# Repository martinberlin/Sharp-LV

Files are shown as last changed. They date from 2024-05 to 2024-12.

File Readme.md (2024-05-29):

### Sharp Low Consumption Versatile PCB

This will host the PCB KiCad files for a  board that aims to be a low consumption driver for SHARP 2.7" MIP LCDs with optional touch.
This is a current work in project and by any means ready to send anywhere to production. The factory we use to produce our prototypes and final PCBs is [JLCPCB.com](https://jlcpcb.com)

### How with touch ?

The person that sold this in eBay had a BTC wallet project that didn't see the light as a product, and combined a Microchip Atmel capacitive touch with a Sharp 400x240 memory LCD:

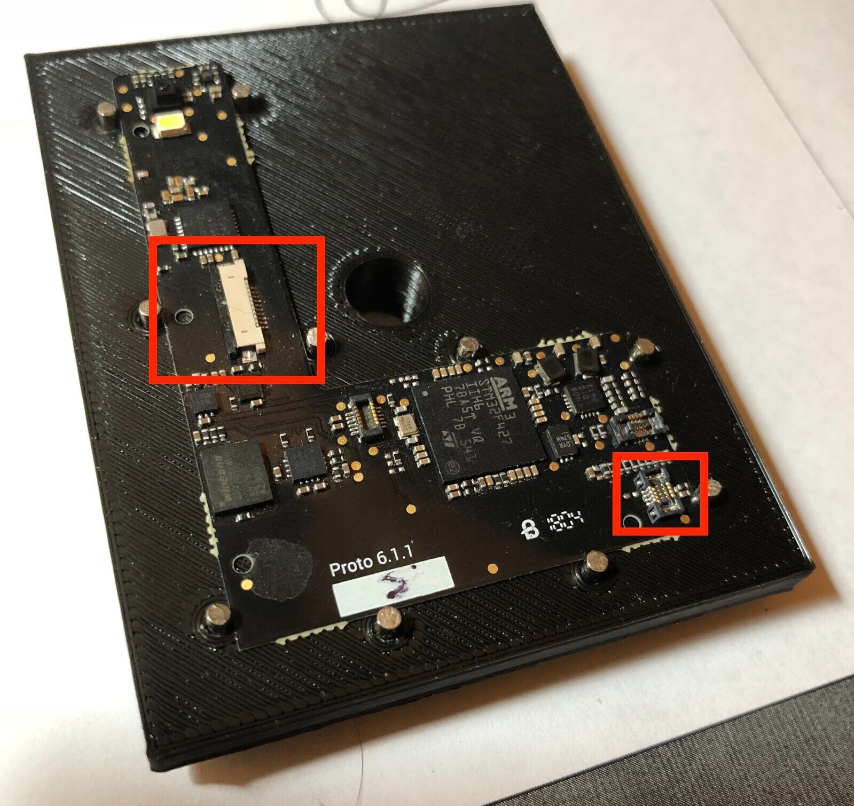
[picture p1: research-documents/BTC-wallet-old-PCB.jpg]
BTC Wallet


Resulting in that he has a nice amount of this combination to sell in eBay.

**TOUCH PINOUT**

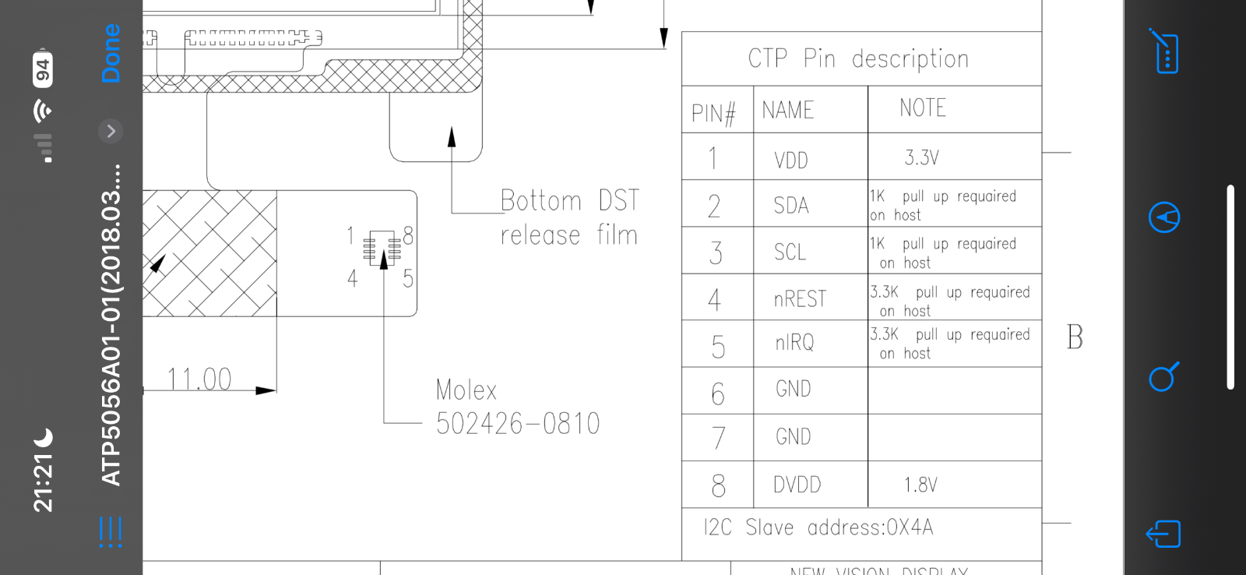
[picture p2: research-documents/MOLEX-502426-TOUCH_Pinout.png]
Atmel pinout


### Goals to achieve with this board

Just a quick wishlist for this PCB wishes, in version 1.0 just want to get the basics working, no add-ons maybe just a QWIIC connector that is cheap:

1. Display working with external Resonator CrystalFonts RV3032 so the MCU can go to sleep and we can keep the LCD running
2. touch connector with the Molex part  C563931
3. Ready for LVGL
4. BLE working at least for 20 meters receiving and sending data packages

### Reference working designs 

[Altium example for nRF52](https://resources.altium.com/p/getting-started-nrf52-mcu-pcb)

[Mike Rankin Oled PCB](https://github.com/mike-rankin/nRF52832_Oled_Board)

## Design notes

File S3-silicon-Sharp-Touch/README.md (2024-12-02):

# SHARP Light and Versatile controller

The goal of this PCB is to make a small SHARP memory in pixel (MIP) controller
All this might change as the idea develops but initially the plan is the following:

- DS3231 or RV2032 acting as RTC to generate the Squarewave required by this displays
- Optional touch only available in eBay from a seller in the UK (Better use 1.1 version)

3D PCB

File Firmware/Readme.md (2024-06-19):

## MaxTouch MXT144

Thanks to Larry Bank [@bitbank2](https://github.com/bitbank2) to be the firt one making the touch work with his [bb_captouch](https://github.com/bitbank2/bb_captouch/) library.
Just load in Arduino IDE the [MaxTouchSharp](https://github.com/martinberlin/Sharp-LV/tree/main/Firmware/MaxTouchSharp) folder. Select any board and connect I2C plus RST pin to the microcontroller. Does not need in my opinion pullup resistances for a quick test although there will be added in the PCB.

### Additional challenge with this MaxTouch device

We should check the [mXT144U Datasheet](https://www.microchip.com/content/dam/mchp/documents/OTH/ProductDocuments/DataSheets/mXT144U%20Touchscreen%20Controller%20Product%20Datasheet.pdf) and see if there is an "interrupt mode" where IRQ pin stays HIGH and goes low when there are messages pending to be read.

### 2 flavours of PCB being designed

1. **Nordic nRF52840** BLE only/ Low consumption (And low experience from my side) you can preview it in this repository, all files open source and MIT licensed. Reviewed by the super helpful and friendly [Nordic engineers in the devZone](https://devzone.nordicsemi.com/f/nordic-q-a/112090/schematics-sanity-check-for-a-sharp-lcd-controller-using-nrf52840)

2. **ESP32-S3FN8** silicon only board w/ BLE & Wi-Fi, made one before so the experience is a bit higher, this one is not **low consumption**. But at least is 240 Mhz and we could try boosting Sharp with LVGL to the max. possible speed.
[Preview both here](https://github.com/martinberlin/Sharp-LV/wiki/PCBs-being-made)

S3 PCB version

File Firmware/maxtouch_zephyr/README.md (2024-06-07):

## Overview

   - For the moment scans I2C addresses in Zephyr

The I2C pins are defined in /boards/espressif/esp32s2_devkitc-pinctrl.dtsi

 :ref:`i2c0_default`.

For the moment I just edited that file manually since I don't know exactly how to extend it in the overlay:

```
 	i2c0_default: i2c0_default {
		group1 {
			pinmux = <I2C0_SDA_GPIO0>,
				 <I2C0_SCL_GPIO1>;
			bias-pull-up;
			drive-open-drain;
			output-high;
		};
	};
```

The source code shows how to:

1. Instance I2C
2. Scan the addresses from 1 to 127
3. Output the first device found and it's address

Requirements
************

Your board must:

* Have I2C enabled, connected to the device, and it must be powered
* Maybe will need pullups in the SDA, SCL lines depending on the device you use

Adding board support
********************

The idea is to port this to a nRF52 but I'm still a newbie on Zephyr!
There is a lot to learn still.

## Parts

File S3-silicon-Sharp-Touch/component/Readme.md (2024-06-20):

### PCB Components

This folder has Symbols, Footprints and 3D Models that are only for this project.

PCB footprint antenna belongs to https://github.com/prasad-dot-ws
and I'm unsure to use it in this design because it does not show the compensated circuit.
This RF tunning needs to be made per board. Is not something you can just copy and paste around.

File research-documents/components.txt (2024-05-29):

COMPONENTS Research & Reference notes

MOLEX female connector
0.4mm 2 Brick nogging Female SMD,P=0.4mm Board-to-Board and Backplane Connector ROHS
https://jlcpcb.com/partdetail/Molex-5024260810/C563931

MCU
https://jlcpcb.com/partdetail/NordicSemicon-NRF52840_QIAAR/C190794 costs 3.05 USD buying 10.

Pin-out:
1..8  1 VDD 3.3V         5   nIRQ (INT) 3.3K pullup
 ||   2 SDA              6&7 GND
4..5  3 SCL
      4 nRST 3.3K pullup

External RTC to make a 50/50 Squarewave for the LCD

https://jlcpcb.com/partdetail/C5127802 
    I2C SON-8(1.5x3.2) Real-Time Clocks(RTC) ROHS

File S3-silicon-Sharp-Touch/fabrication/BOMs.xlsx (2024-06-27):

Designator | Footprint | Comment | JLCPCB Part #
J1 | USB_C_Receptacle_HRO_TYPE-C-31-M-12 | USB_C_Receptacle_USB2.0 | C165948
R3,R5,R6 | R_0603_1608Metric | 10k | C25804
X1 | Crystal_ECS-40Mhz_ECS | Crystal 40 Mhz 10ppm | C555614
C4,C1,C2 | C_0805_2012Metric | 10uF | C15850
RN1 | R_Array_Concave_4x0402 | R_Pack04 | C728735
C7,C6,C5,C8 | C_0603_1608Metric | 0.1uF | C3846795
L1,L2 | L_0603_1608Metric | L | C1027
R1,R11,R14,R15 | R_0603_1608Metric | 5.1k | C23186
D6 | LED_0805_2012Metric | GRE | C2297
R7,R8,R9,R10 | R_0402_1005Metric | 3.3k | C5224103
Q2,Q1 | SOT-23 | MMBT3904 | C20526
D2,D1,D4,D3 | LED_0805_2012Metric | LED | C2297
BT1 | CoinBattery_MS621FE | Battery_Cell | C80909
J6 | CON_Molex_5024260812 | 5024260810 | C563931
C3,C9 | C_0603_1608Metric | 1uF | C525331
Q3 | SOT-23 | Si2301CDS | C10487
C15,C14 | C_0805_2012Metric | 12pF | C1792
C10,C11 | C_0603_1608Metric | 22pF | C561172
R4 | R_0603_1608Metric | 0Ω | C21189
C12 | C_0603_1608Metric | 2pF | C162216
R13 | R_0805_2012Metric | 2K2 | C17520
J7 | S2BPHSM4TBLFSN | S2B-PH-SM4-TB_LF__SN_ | C295747
Y1 | Crystal_SMD_3215-2Pin_3.2x1.5mm | 32.768K | C32346
U4 | SOIC-8_3.9x4.9mm_P1.27mm | DS3231MZ | C107410
IC1 | ESP32-S3FN8-QFN40P700X700X90-57N-D | ESP32-S3FN8 | C2913196
D5 | D_SOD-123 | 1N5817 | C8598
U1 | TSOT-23-5 | RT9080-33GJ5 | C841192
R16 | R_0603_1608Metric | 10 K | C25804
C13 | C_0603_1608Metric | 2.4pF | C5448887
D7 | LED_0805_2012Metric | RED | C84256
U3 | TP4057-42-SOT26-R | TP4057-42-SOT26-R | C12044
ANT1 | 2450AT42E0100E-ANT | 2450AT42E0100E | C3285081
R12 | R_0603_1608Metric | 10K | C25804
J5 | FH5210S05SH99_LCD | FH52-10S-0.5SH_99 | C598038
U2 | SOT-666 | USBLC6-2P6 | C2827693

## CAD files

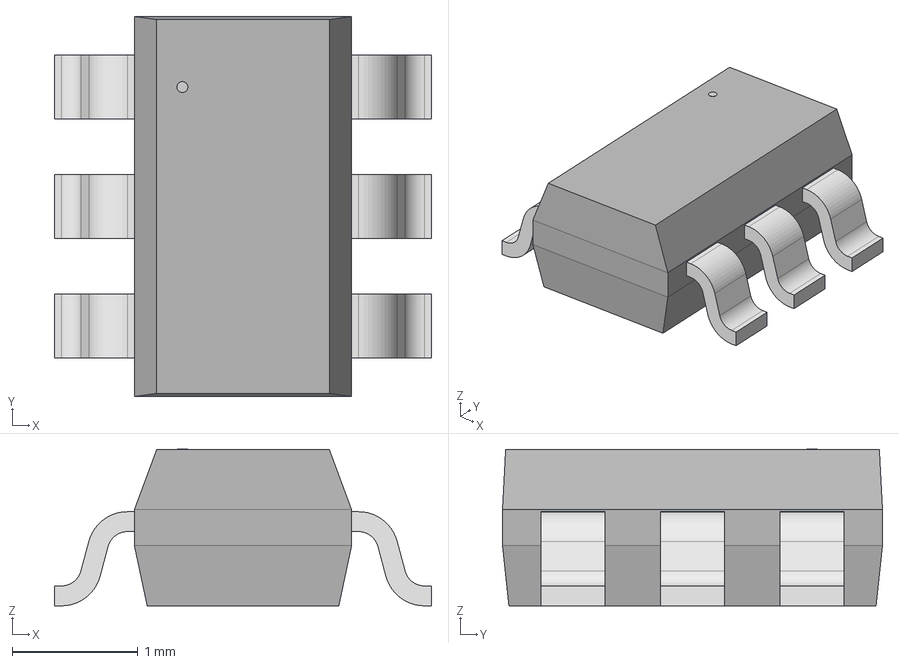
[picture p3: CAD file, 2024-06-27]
components/3D/TP4057-SOT-23.step
3.00 x 3.02 x 1.25 mm

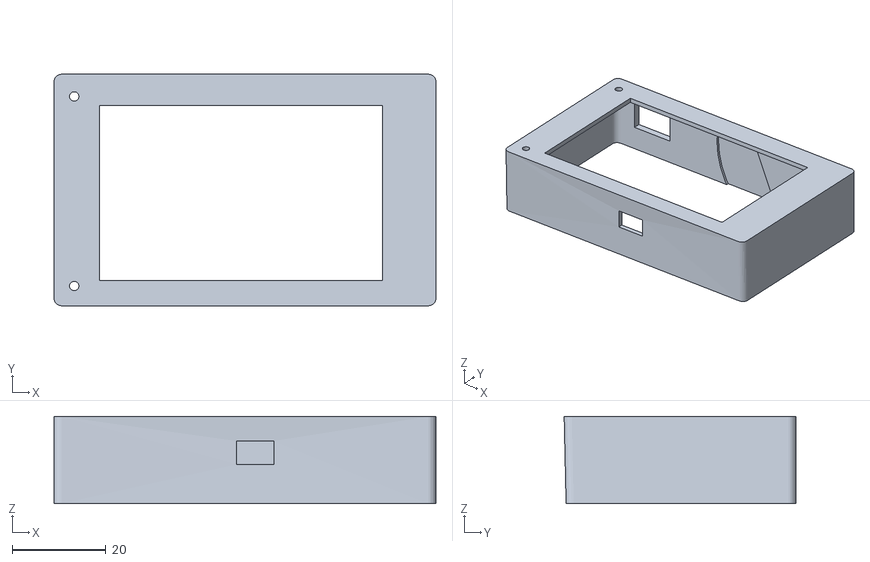
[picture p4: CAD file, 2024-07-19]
enclosure/SHARP-S3-battery-TOP.stl
81.4 x 49.4 x 18.6

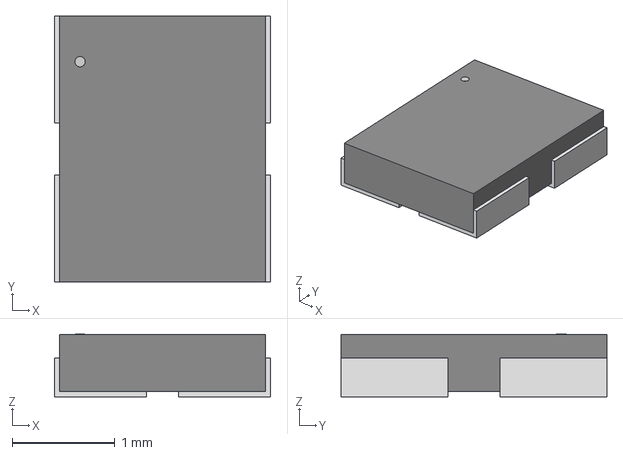
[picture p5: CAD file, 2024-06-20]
S3-silicon-Sharp-Touch/component/3d/Crytal_ECS-40Mhz_ECS.step
2.11 x 2.59 x 0.612 mm

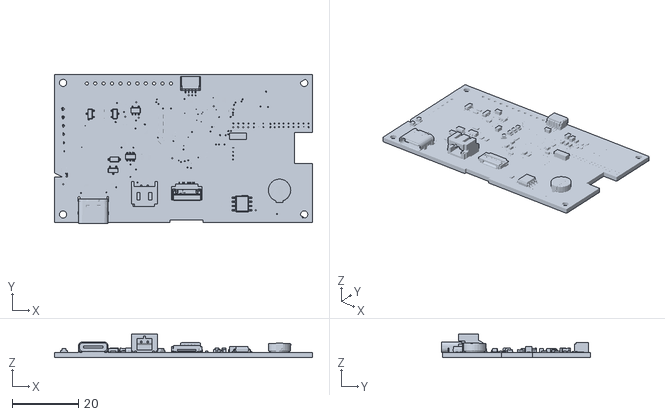
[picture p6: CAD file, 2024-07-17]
S3-silicon-Sharp-Touch/fabrication/3D/S3-silicon-Sharp-Touch-3D.stl
77.9 x 44.8 x 7.17

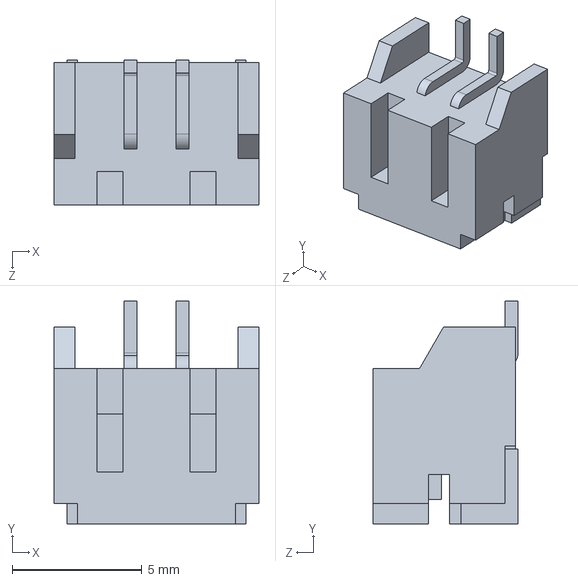
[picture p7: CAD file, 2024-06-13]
components/3D/S2B-PH-SM4-TB_LF__SN_.stp
7.90 x 8.60 x 5.60 mm

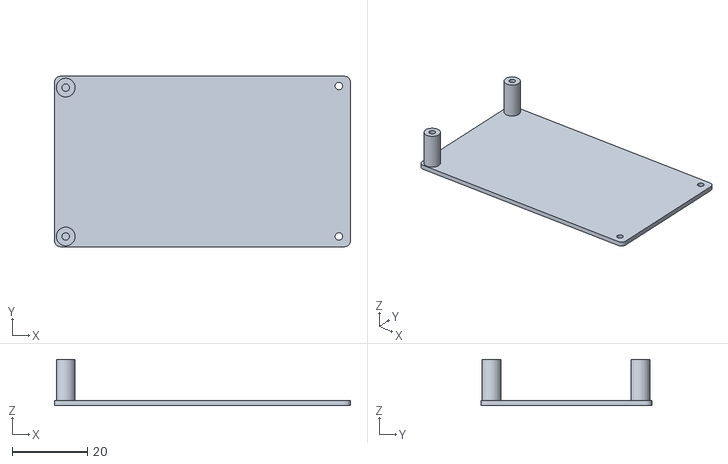
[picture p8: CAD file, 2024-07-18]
enclosure/SHARP-S3-battery-BOTTOM.stl
78.8 x 45.4 x 12.3

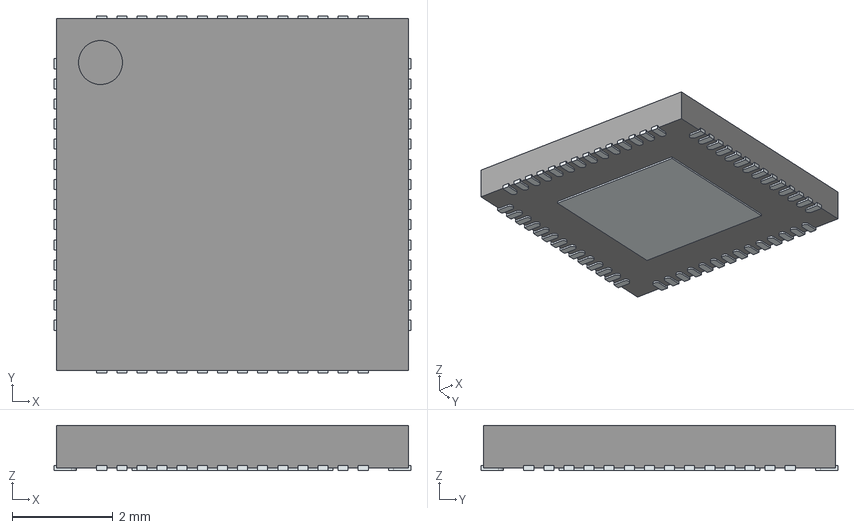
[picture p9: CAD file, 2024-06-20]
S3-silicon-Sharp-Touch/component/3d/ESP32-S3FN8.stp
7.10 x 7.10 x 0.9 mm
ThermalPin
PinsArrayLR
PinsArrayTB

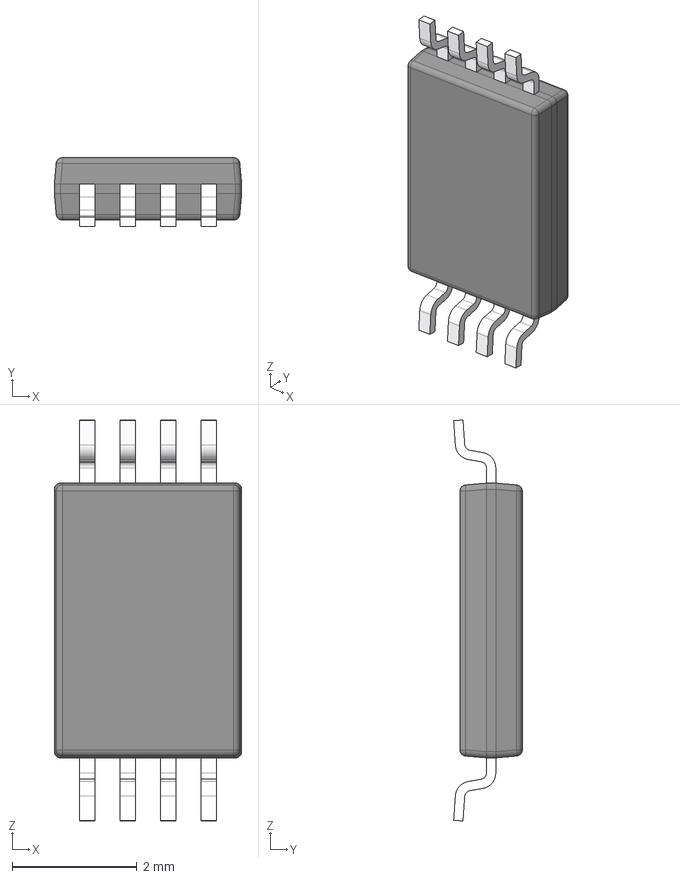
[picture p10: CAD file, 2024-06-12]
components/3D/TPS2113APWR.stp
3.00 x 1.10 x 6.42 mm
BODY-SO
LEAD-SO x 8
PIN1-ID

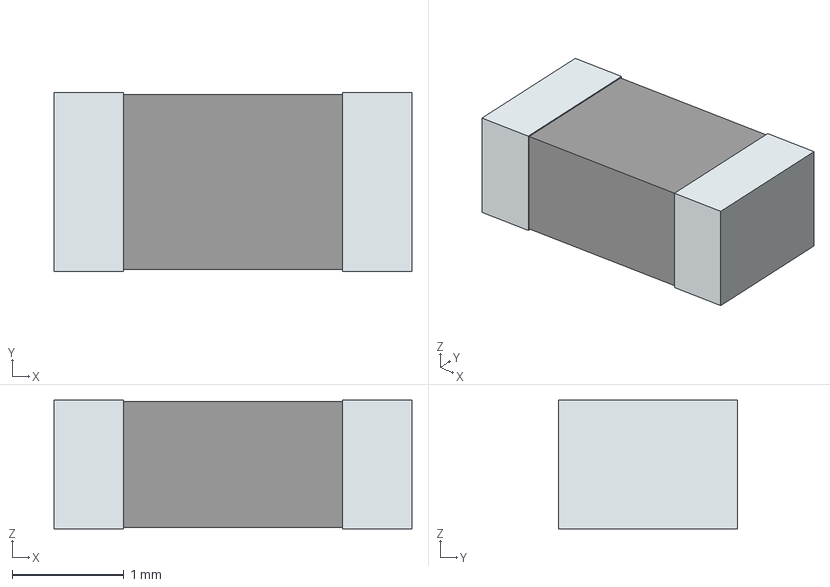
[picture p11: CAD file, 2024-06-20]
S3-silicon-Sharp-Touch/component/3d/W3008-Antenna.step
3.20 x 1.60 x 1.15 mm
term1
term2

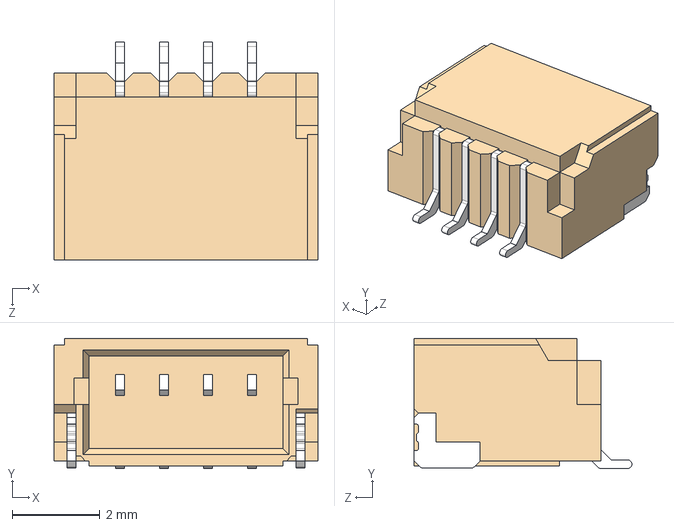
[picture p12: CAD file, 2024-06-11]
components/3D/QWIIC_SM04B-SRSS-TB_LF__SN_.stp
6.00 x 2.96 x 4.95 mm

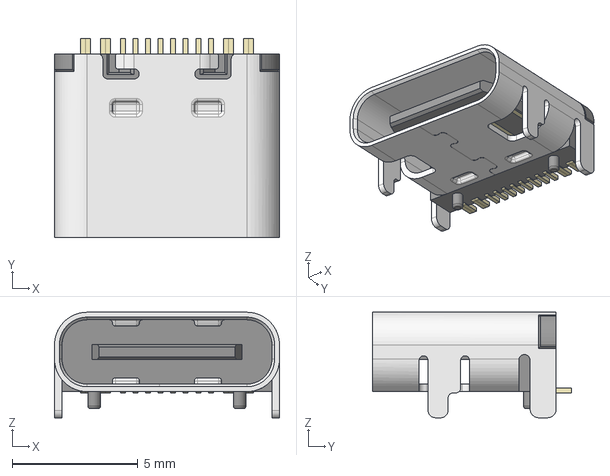
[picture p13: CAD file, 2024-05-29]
S3-silicon-Sharp-Touch/component/3d/USB_TYPE-C-31-M-12.step
8.95 x 7.90 x 4.20 mm

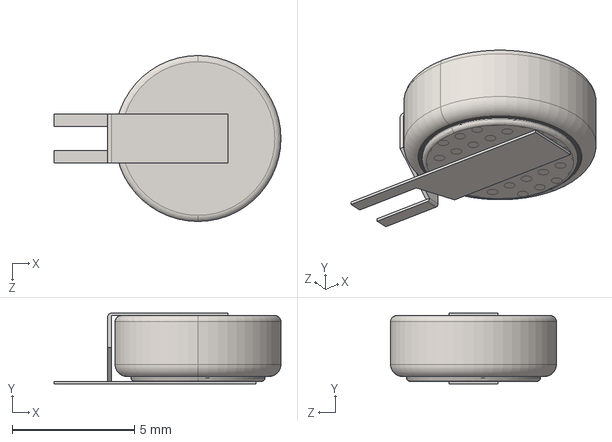
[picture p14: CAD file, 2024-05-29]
components/3D/CoinBattery_MS621FE-FL11E.stp
9.30 x 2.90 x 6.80 mm

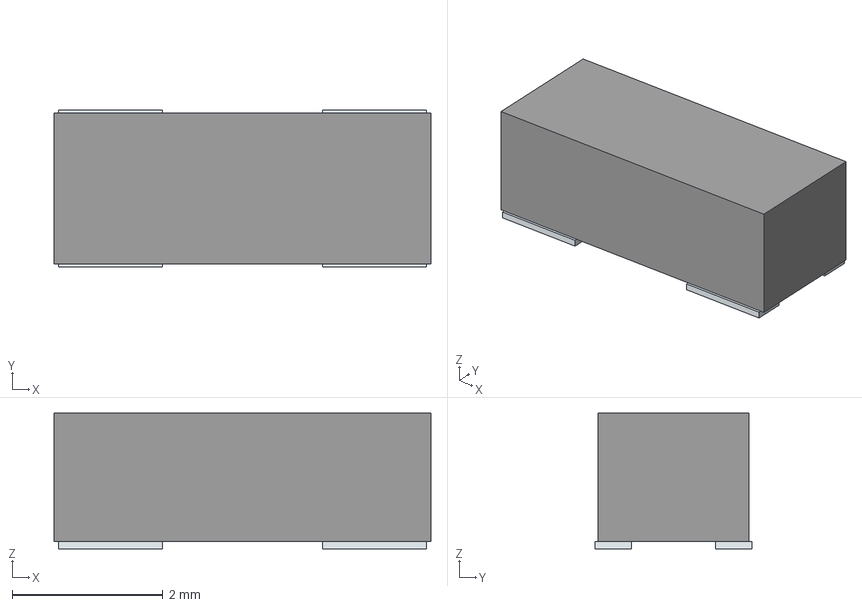
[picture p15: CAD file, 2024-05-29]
S3-silicon-Sharp-Touch/component/3d/2450AT42E0100E-ANT.stp
5.00 x 2.08 x 1.80 mm
Pins

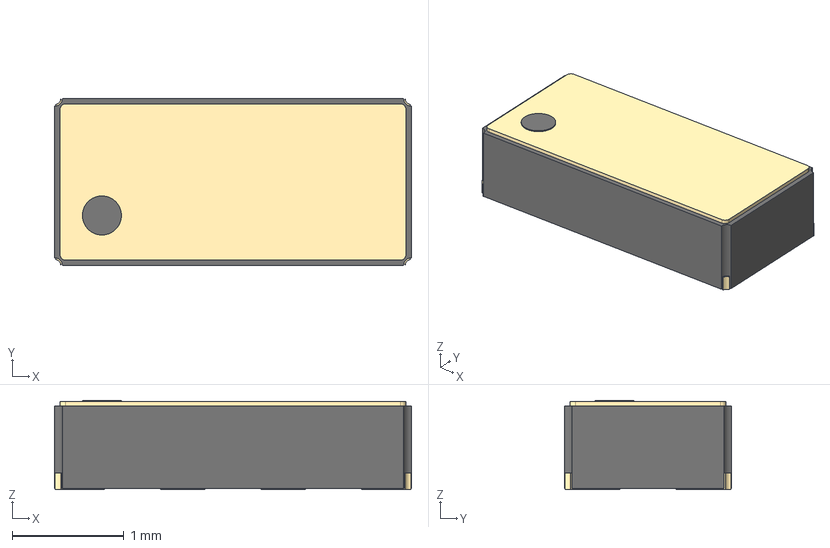
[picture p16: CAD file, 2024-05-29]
components/3D/RV-3032-C7.stp
3.20 x 1.50 x 0.8 mm
Rect2
Rect3
Rect4
Rect5
Terminal

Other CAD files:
components/3D/LCD-10S-0.5SH.step
components/3D/MOLEX_502426-0810.stp
components/3D/NRF52840-QIAA-R.stp
enclosure/SHARP-S3-battery.blend

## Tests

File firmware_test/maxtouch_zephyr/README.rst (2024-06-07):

.. zephyr:code-sample:: maxtouch
   :name: Maxtouch
   :relevant-api: gpio_interface i2c

   For the moment scans I2C addresses in Zephyr

Overview
********

The I2C pins are defined in /boards/espressif/esp32s2_devkitc-pinctrl.dtsi

 :ref:`i2c0_default`.

 For the moment I just edited that file manually since I don't know exactly how to extend it in the overlay:

```
 	i2c0_default: i2c0_default {
		group1 {
			pinmux = <I2C0_SDA_GPIO0>,
				 <I2C0_SCL_GPIO1>;
			bias-pull-up;
			drive-open-drain;
			output-high;
		};
	};
```

The source code shows how to:

#. Instance I2C
#. Scan the addresses from 1 to 127
#. Output the first device found and it's address

Requirements
************

Your board must:

#. Have I2C enabled
#. Maybe will need pullups in the SDA, SCL lines depending on the device you use

Adding board support
********************

The idea is to port this to a nRF52 but I'm still a newbie on Zephyr!
There is a lot to learn still.

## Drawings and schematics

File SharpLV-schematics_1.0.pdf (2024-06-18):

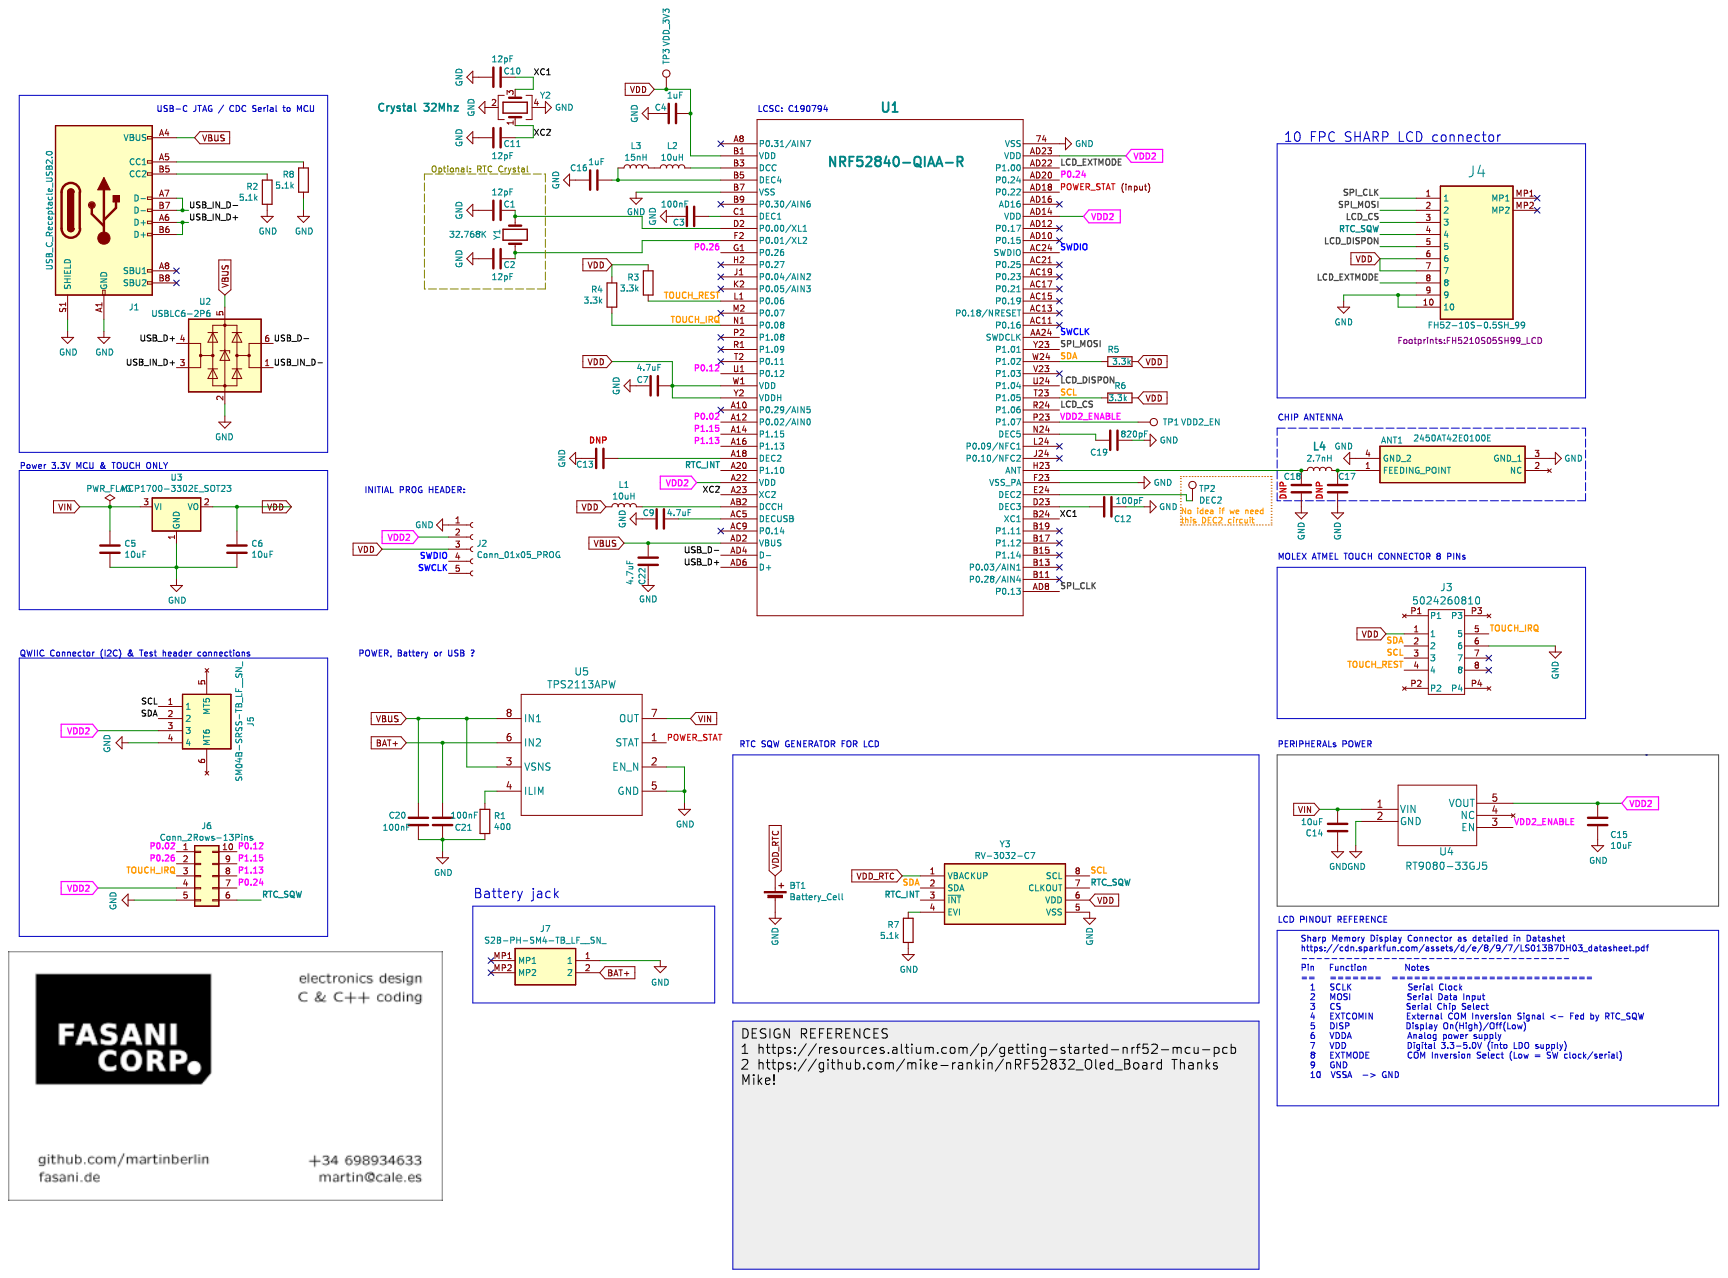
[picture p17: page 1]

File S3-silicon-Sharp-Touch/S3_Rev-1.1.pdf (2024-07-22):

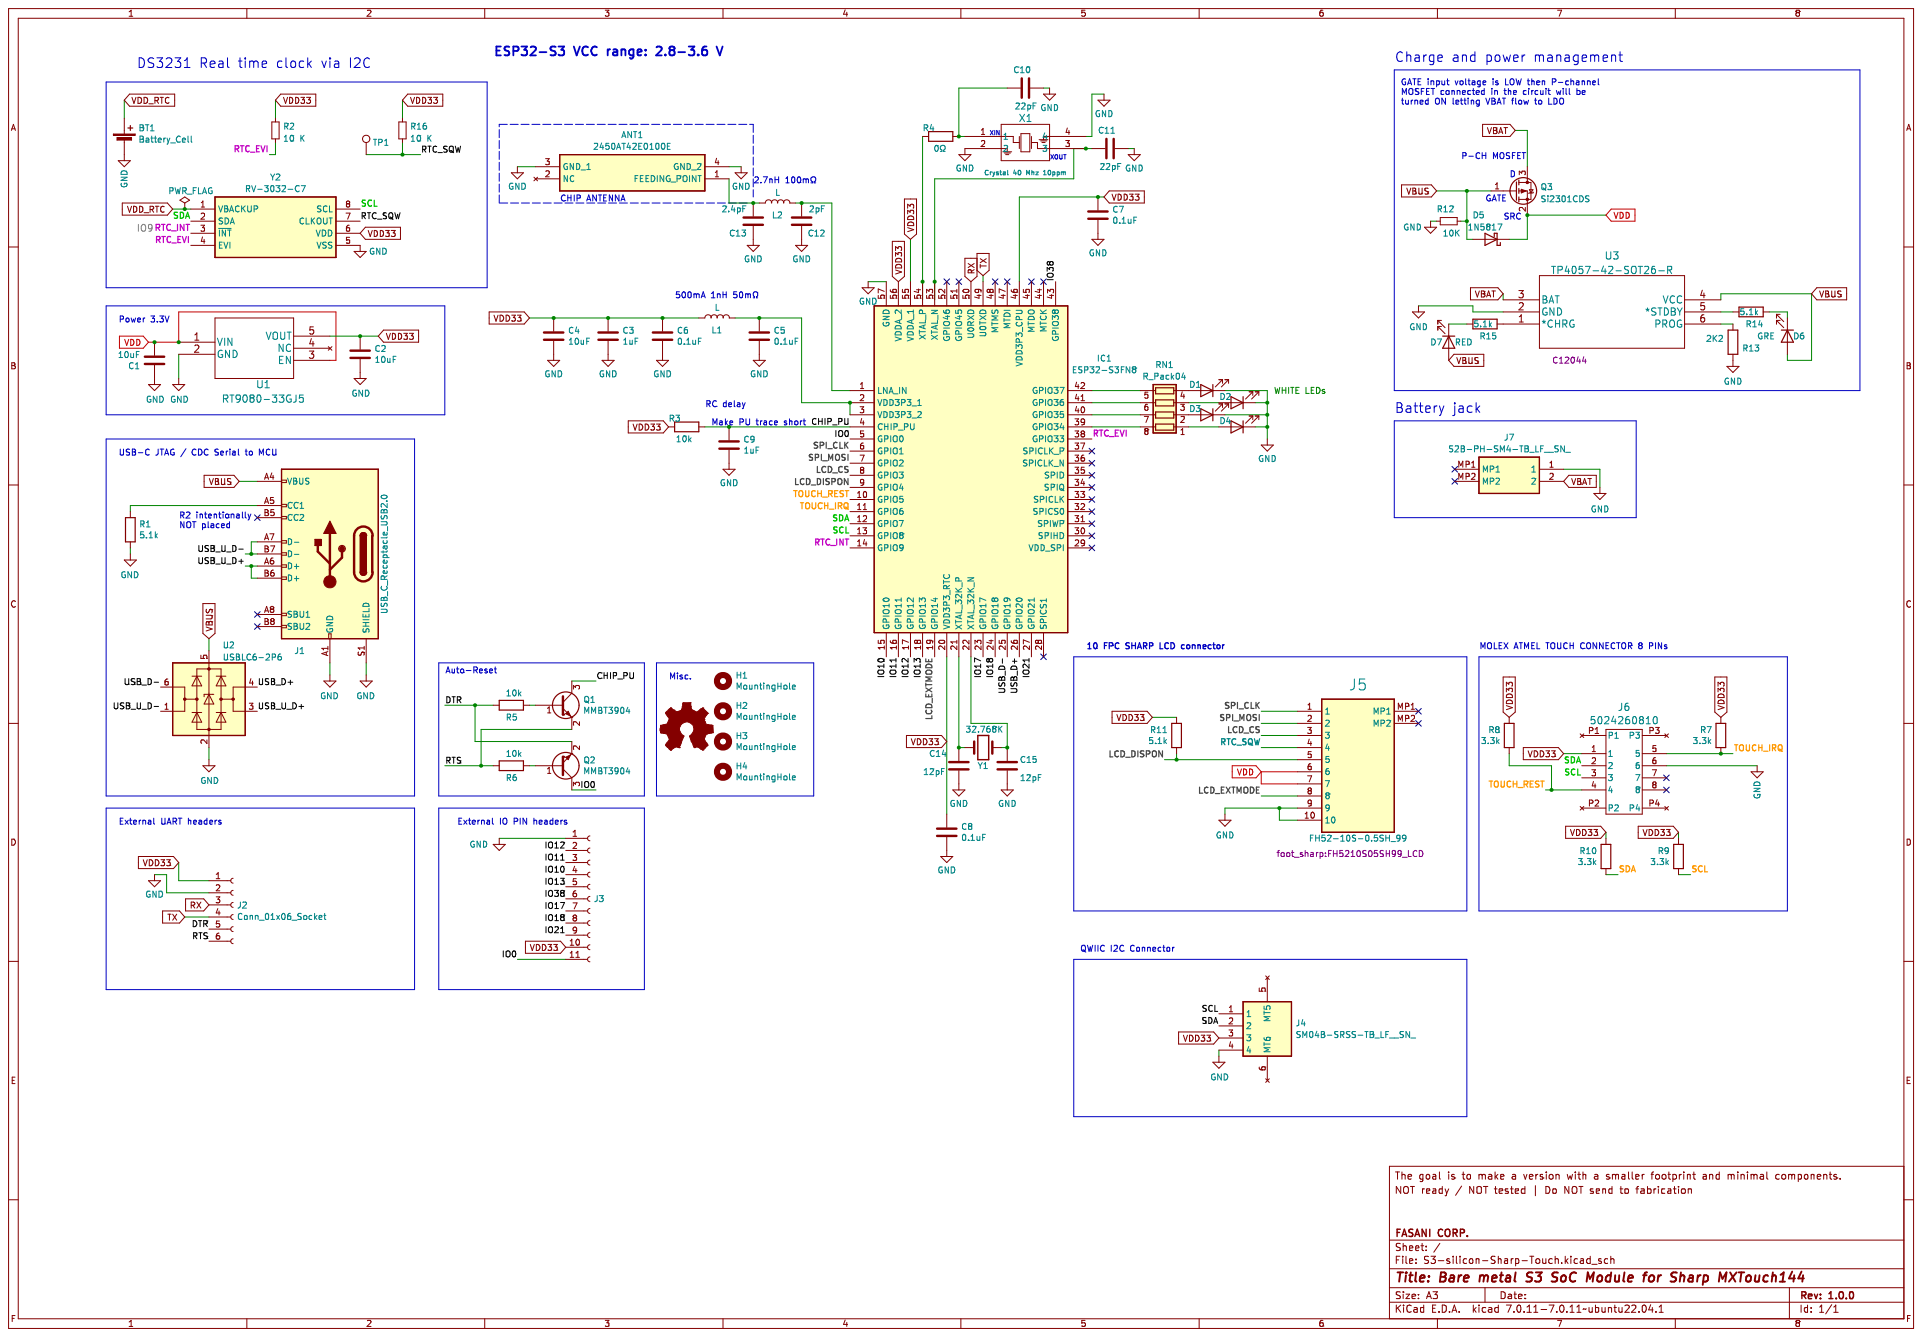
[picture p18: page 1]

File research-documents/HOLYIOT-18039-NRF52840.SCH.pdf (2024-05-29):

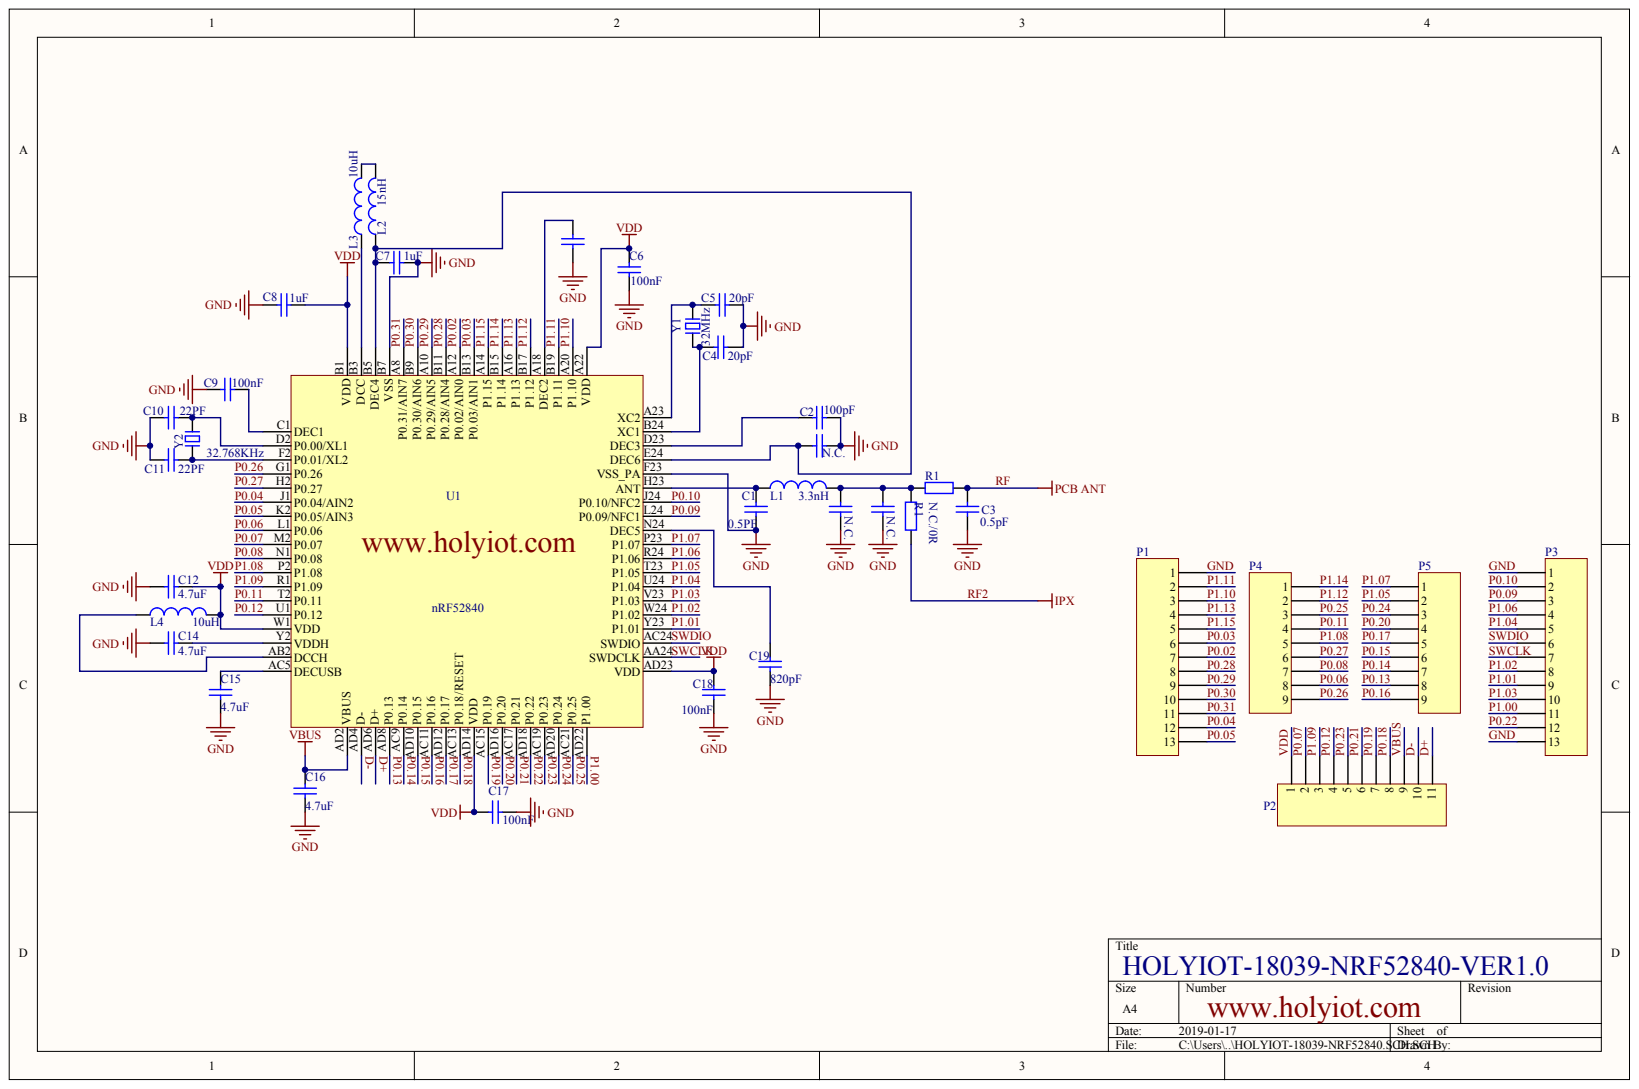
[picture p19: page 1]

VDD AD23 SWDCLK AA24 SWDIO AC24 P1.01 Y23 P1.02 W24 P1.03 V23 P1.04 U24 P1.05 T23 P1.06 R24 P1.07 P23 DEC5 N24 P0.09/NFC1 L24 P0.10/NFC2 J24 ANT H23 VSS_PA F23 DEC6 E24 DEC3 D23 XC1 B24 XC2 A23

VDD A22 P1.10 A20 P1.11 B19 DEC2 A18 P1.12 B17 P1.13 A16 P1.14 B15 P1.15 A14 P0.03/AIN1 B13 P0.02/AIN0 A12 P0.28/AIN4 B11 P0.29/AIN5 A10 P0.30/AIN6 B9 P0.31/AIN7 A8 VSS B7 DEC4 B5 DCC B3 VDD B1 VBUS AD2

P0.04/AIN2 J1 | P0.10 C1 0.5PF
P0.05/AIN3 K2 | P0.09

P0.07 M2 | P1.07
P0.08 N1 | P1.06 GND | RF2

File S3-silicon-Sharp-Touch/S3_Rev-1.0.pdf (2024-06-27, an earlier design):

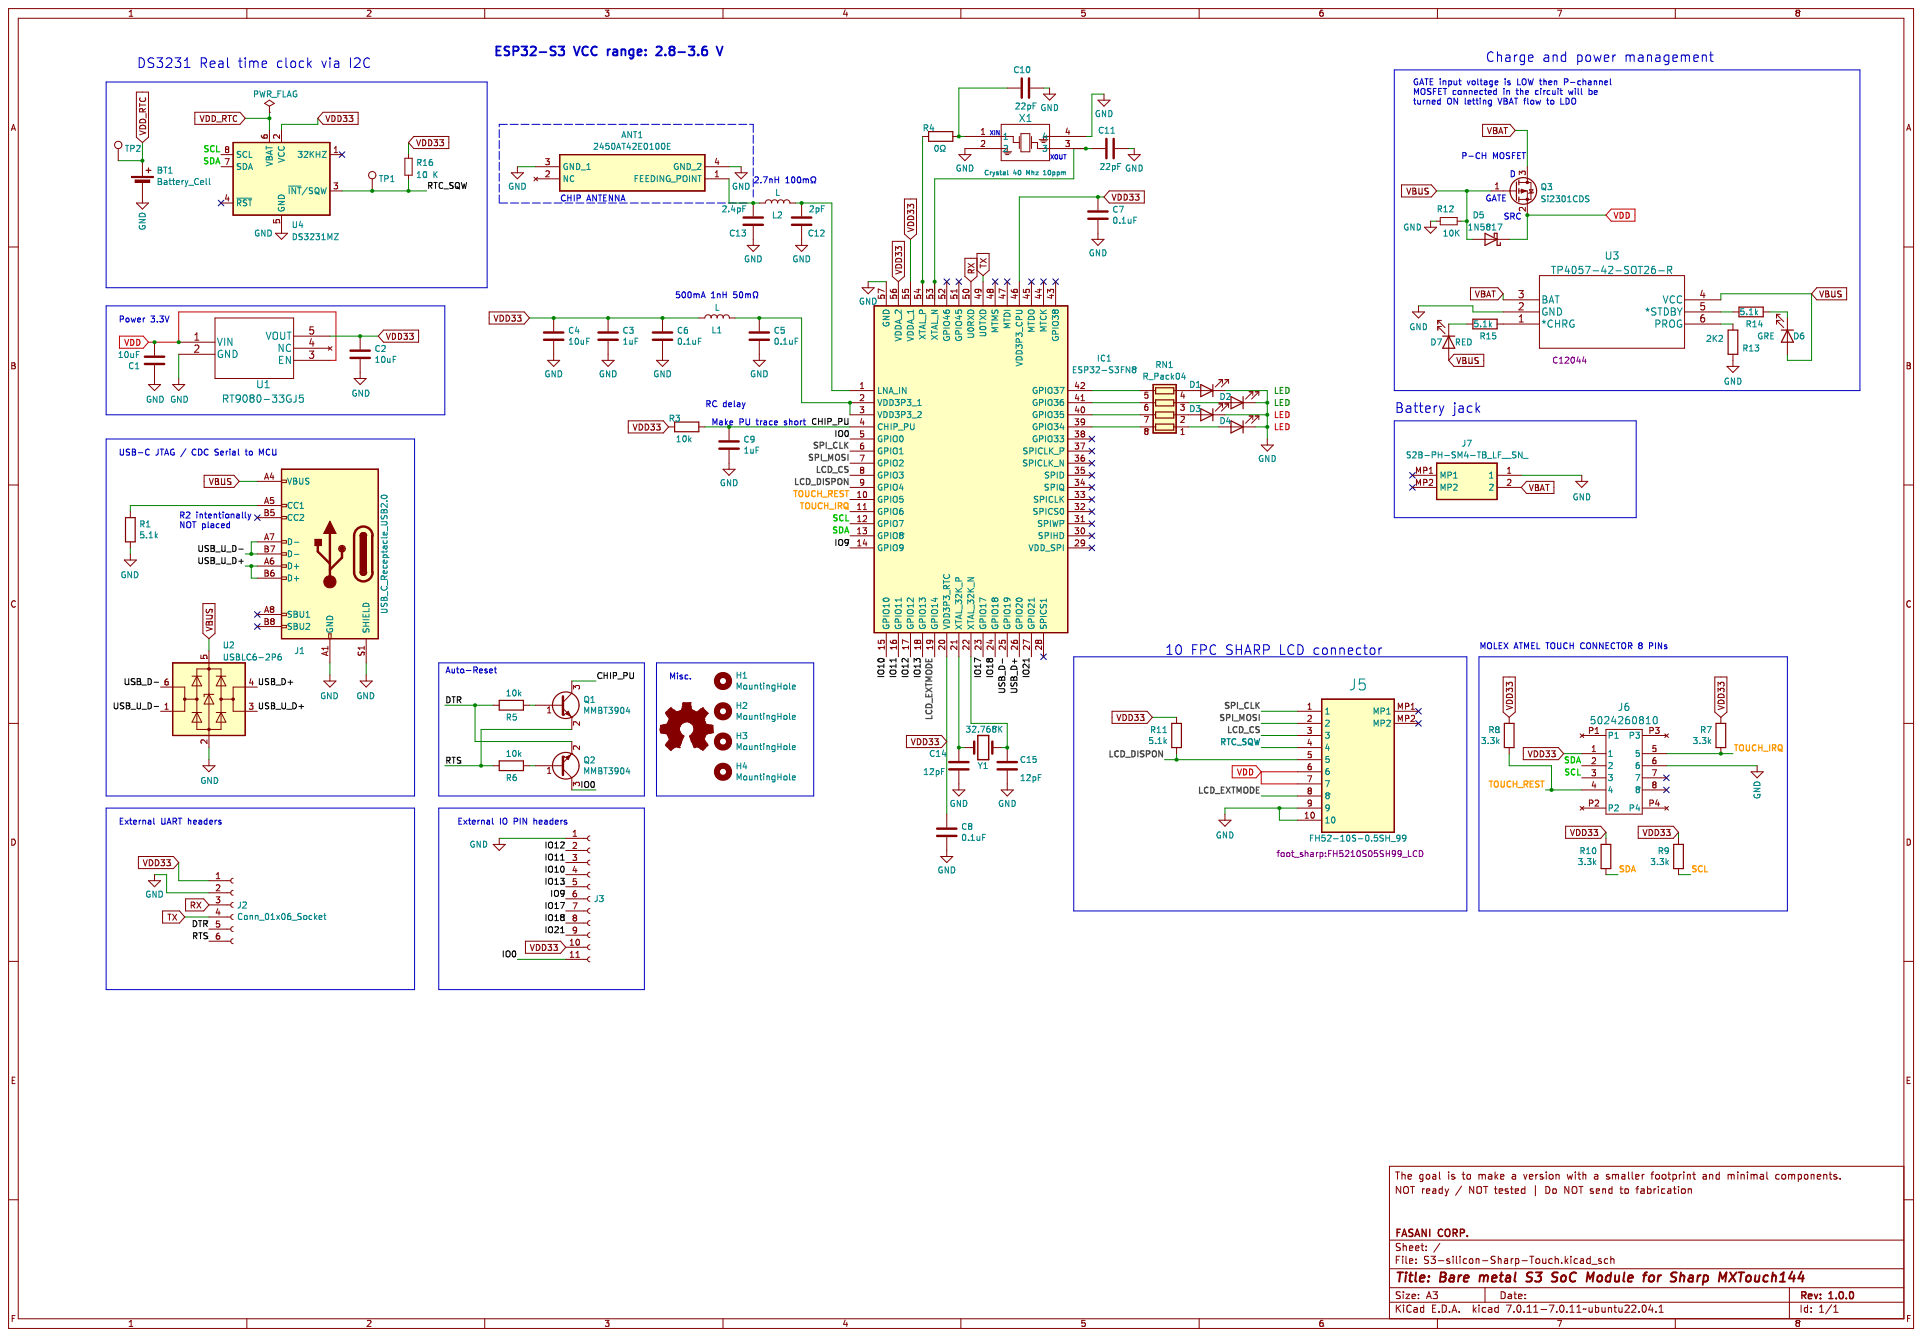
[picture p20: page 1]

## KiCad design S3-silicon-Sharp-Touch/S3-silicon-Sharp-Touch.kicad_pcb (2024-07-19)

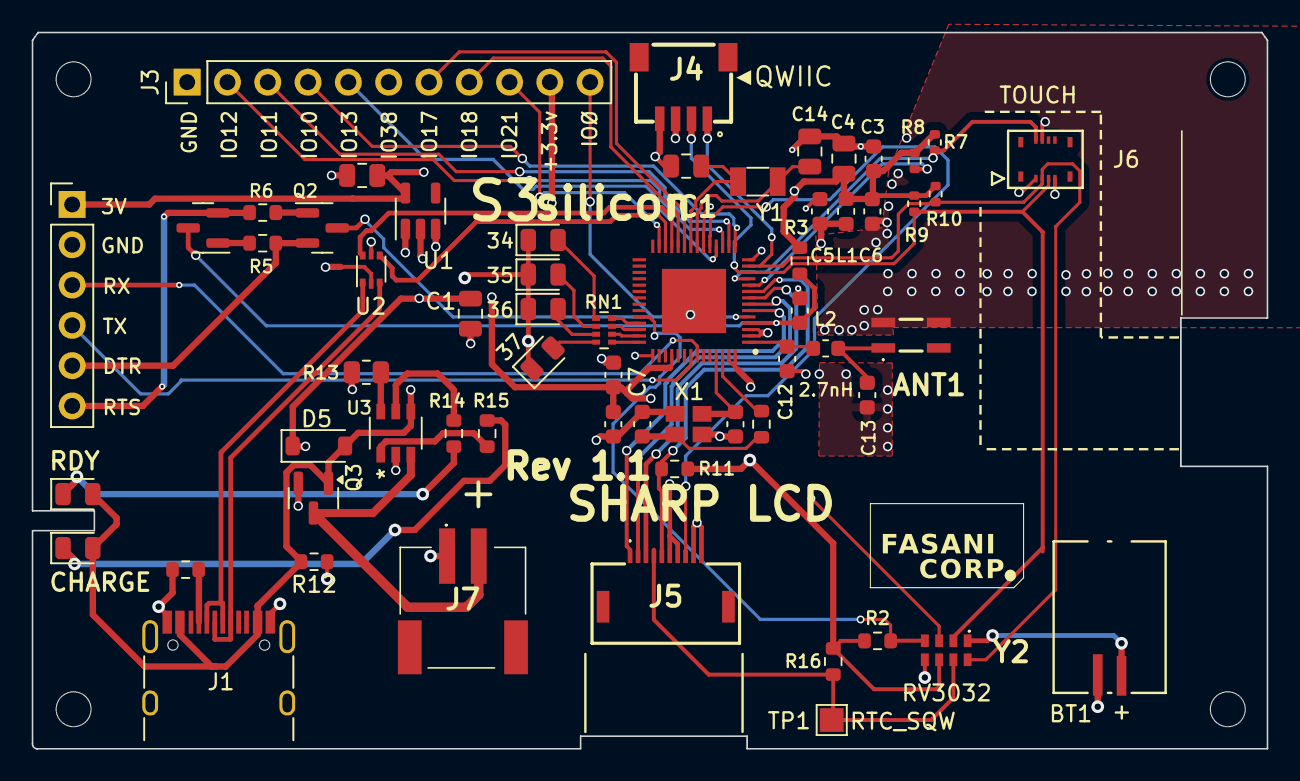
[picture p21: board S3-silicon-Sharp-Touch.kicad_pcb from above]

Board: 4 copper layers, 77.8 x 45.2 mm, 65 parts (0 on the bottom side), 60 nets.

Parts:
ANT1: 2450AT42E0100E; 2450AT42E0100E-ANT
BT1: Battery_Cell; CoinBattery_MS621FE
C1, C2, C4: 10uF; C_0805_2012Metric
C3, C9: 1uF; C_0603_1608Metric
C5, C6, C7, C8: 0.1uF; C_0603_1608Metric
C10, C11: 22pF; C_0603_1608Metric
C12: 2pF; C_0603_1608Metric
C13: 2.4pF; C_0603_1608Metric
C14, C15: 12pF; C_0805_2012Metric
D1: LED GREEN; LED_0805_2012Metric
D2, D3: LED; LED_0805_2012Metric
D4: LED RED; LED_0805_2012Metric
D5: 1N5817; D_SOD-123
D6: GRE; LED_0805_2012Metric
D7: RED; LED_0805_2012Metric
H1, H2, H3, H4: MountingHole; MountingHole_2.2mm_M2
IC1: ESP32-S3FN8; ESP32-S3FN8-QFN40P700X700X90-57N-D
J1: USB_C_Receptacle_USB2.0; USB_C_Receptacle_HRO_TYPE-C-31-M-12
J2: Conn_01x06_Socket; PinHeader_1x06_P2.54mm_Vertical
J3: Conn_01x11_Socket; PinHeader_1x11_P2.54mm_Vertical
J4: SM04B-SRSS-TB_LF__SN_; QWIIC_SM04B-SRSS-TB_LFSN_
J5: FH52-10S-0.5SH_99; FH5210S05SH99_LCD
J6: 5024260810; CON_Molex_5024260812
J7: S2B-PH-SM4-TB_LF__SN_; S2BPHSM4TBLFSN
L1, L2: L; L_0603_1608Metric
Q1, Q2: MMBT3904; SOT-23
Q3: Si2301CDS; SOT-23
R1, R11, R14, R15: 5.1k; R_0603_1608Metric
R2, R16: 10 K; R_0603_1608Metric
R3, R5, R6: 10k; R_0603_1608Metric
R4: 0Ω; R_0603_1608Metric
R7, R8, R9, R10: 3.3k; R_0402_1005Metric
R12: 10K; R_0603_1608Metric
R13: 2K2; R_0805_2012Metric
RN1: R_Pack04; R_Array_Concave_4x0402
TP1: RTC_INT; TestPoint_Pad_1.5x1.5mm
U1: RT9080-33GJ5; TSOT-23-5
U2: USBLC6-2P6; SOT-666
U3: TP4057-42-SOT26-R
X1: Crystal 40 Mhz 10ppm; Crystal_ECS-40Mhz_ECS
Y1: 32.768K; Crystal_SMD_3215-2Pin_3.2x1.5mm
Y2: RV-3032-C7; RV3032C7

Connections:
/CHIP_PU: C9.2, IC1.4 (CHIP_PU), Q1.3 (C), R3.2
/DTR: J2.5, Q2.2 (E), R5.2
/IO0: IC1.5 (GPIO0), J3.11, Q2.3 (C)
/IO10: IC1.15 (GPIO10), J3.4
/IO11: IC1.16 (GPIO11), J3.3
/IO12: IC1.17 (GPIO12), J3.2
/IO13: IC1.18 (GPIO13), J3.5
/IO17: IC1.23 (GPIO17), J3.7
/IO18: IC1.24 (GPIO18), J3.8
/IO21: IC1.27 (GPIO21), J3.9
/IO38: IC1.43 (GPIO38), J3.6
/LCD_CS: IC1.8 (GPIO3), J5.3
/LCD_DISPON: IC1.9 (GPIO4), J5.5, R11.2
/LCD_EXTMODE: IC1.19 (GPIO14), J5.8
/RTC_EVI: IC1.38 (GPIO33), R2.2, Y2.4 (EVI)
/RTC_INT: IC1.14 (GPIO9), Y2.3 (~INT)
/RTC_SQW: J5.4, R16.2, TP1.1, Y2.7 (CLKOUT)
/RTS: J2.6, Q1.2 (E), R6.2
/SCL: IC1.13 (GPIO8), J4.1, J6.3, R9.2, Y2.8 (SCL)
/SDA: IC1.12 (GPIO7), J4.2, J6.2, R10.2, Y2.2 (SDA)
/SPI_CLK: IC1.6 (GPIO1), J5.1
/SPI_MOSI: IC1.7 (GPIO2), J5.2
/TOUCH_IRQ: IC1.11 (GPIO6), J6.5, R7.2
/TOUCH_REST: IC1.10 (GPIO5), J6.4, R8.2
/USB_D+: IC1.26 (GPIO20), U2.4 (I/O2)
/USB_D-: IC1.25 (GPIO19), U2.6 (I/O1)
/USB_U_D+: J1.A6 (D+), J1.B6 (D+), U2.3 (I/O2)
/USB_U_D-: J1.A7 (D-), J1.B7 (D-), U2.1 (I/O1)
GND: ANT1.3 (GND_1), ANT1.4 (GND_2), BT1.2 (-), C1.2, C2.1, C3.1, C4.1, C5.1, C6.1, C7.1, C8.1, C9.1, C10.1, C11.1, C12.2, C13.2, C14.1, C15.1, D1.1 (K), D2.1 (K), D3.1 (K), D4.1 (K), IC1.57 (GND), J1.A1 (GND), J1.A12 (GND), J1.B1 (GND), J1.B12 (GND), J1.S1 (SHIELD), J2.2, J3.1, J4.4, J5.9, J5.10, J6.6, J7.1, R1.2, R12.1, R13.1, U1.2 (GND), U2.2 (GND), U3.2 (GND), X1.2, X1.4, Y2.5 (VSS)
unnamed: ANT1.1 (FEEDING_POINT), C13.1, L2.1
unnamed: C10.2, R4.2, X1.1
unnamed: D1.2 (A), RN1.4 (R4.1)
unnamed: D2.2 (A), RN1.3 (R3.1)
unnamed: D3.2 (A), RN1.2 (R2.1)
unnamed: D4.2 (A), RN1.1 (R1.1)
unnamed: D6.1 (K), R14.1
unnamed: D7.1 (K), R15.2
unnamed: IC1.39 (GPIO34), RN1.8 (R1.2)
unnamed: IC1.40 (GPIO35), RN1.7 (R2.2)
unnamed: IC1.41 (GPIO36), RN1.6 (R3.2)
unnamed: IC1.42 (GPIO37), RN1.5 (R4.2)
unnamed: C12.1, IC1.1 (LNA_IN), L2.2
unnamed: C5.2, IC1.2 (VDD3P3_1), IC1.3 (VDD3P3_2), L1.2
unnamed: C15.2, IC1.22 (XTAL_32K_N), Y1.2
unnamed: C14.2, IC1.21 (XTAL_32K_P), Y1.1
unnamed: C11.2, IC1.53 (XTAL_N), X1.3
unnamed: IC1.54 (XTAL_P), R4.1
unnamed: J1.A5 (CC1), R1.1
unnamed: Q1.1 (B), R5.1
unnamed: Q2.1 (B), R6.1
unnamed: R15.1, U3.1 (*CHRG)
unnamed: R14.2, U3.5 (*STDBY)
unnamed: R13.2, U3.6 (PROG)
RX: IC1.50 (U0RXD), J2.3
TX: IC1.49 (U0TXD), J2.4
VBAT: J7.2, Q3.3 (D), U3.3 (BAT)
VBUS: D5.2 (A), D6.2 (A), D7.2 (A), J1.A4 (VBUS), J1.A9 (VBUS), J1.B4 (VBUS), J1.B9 (VBUS), Q3.1 (G), R12.2, U2.5 (VBUS), U3.4 (VCC)
VDD: C1.1, D5.1 (K), J5.6, J5.7, Q3.2 (S), U1.1 (VIN), U1.3 (EN)
VDD33: C2.2, C3.2, C4.2, C6.2, C7.2, C8.2, IC1.20 (VDD3P3_RTC), IC1.46 (VDD3P3_CPU), IC1.55 (VDDA_1), IC1.56 (VDDA_2), J2.1, J3.10, J4.3, J6.1, L1.1, R2.1, R3.1, R7.1, R8.1, R9.1, R10.1, R11.1, R16.1, U1.5 (VOUT), Y2.6 (VDD)
VDD_RTC: BT1.1 (+), Y2.1 (VBACKUP)

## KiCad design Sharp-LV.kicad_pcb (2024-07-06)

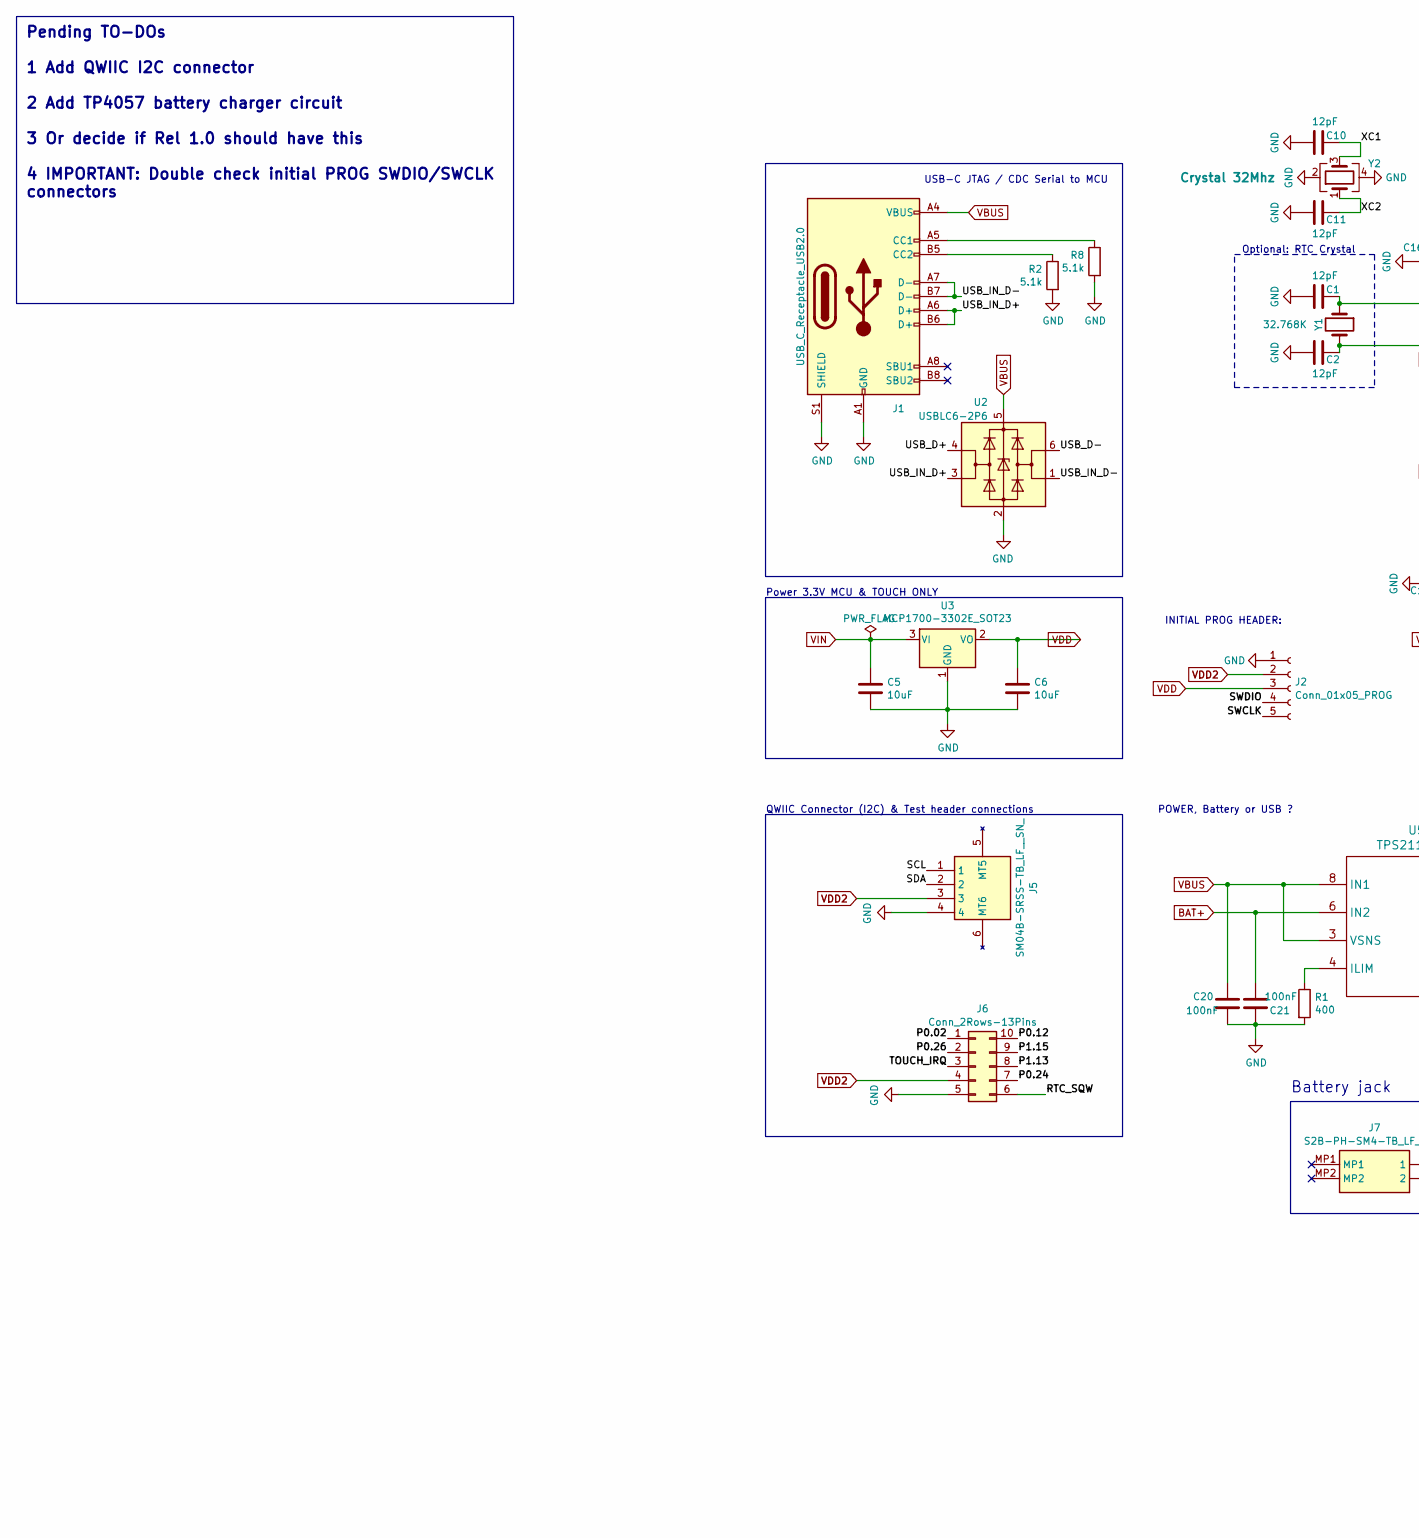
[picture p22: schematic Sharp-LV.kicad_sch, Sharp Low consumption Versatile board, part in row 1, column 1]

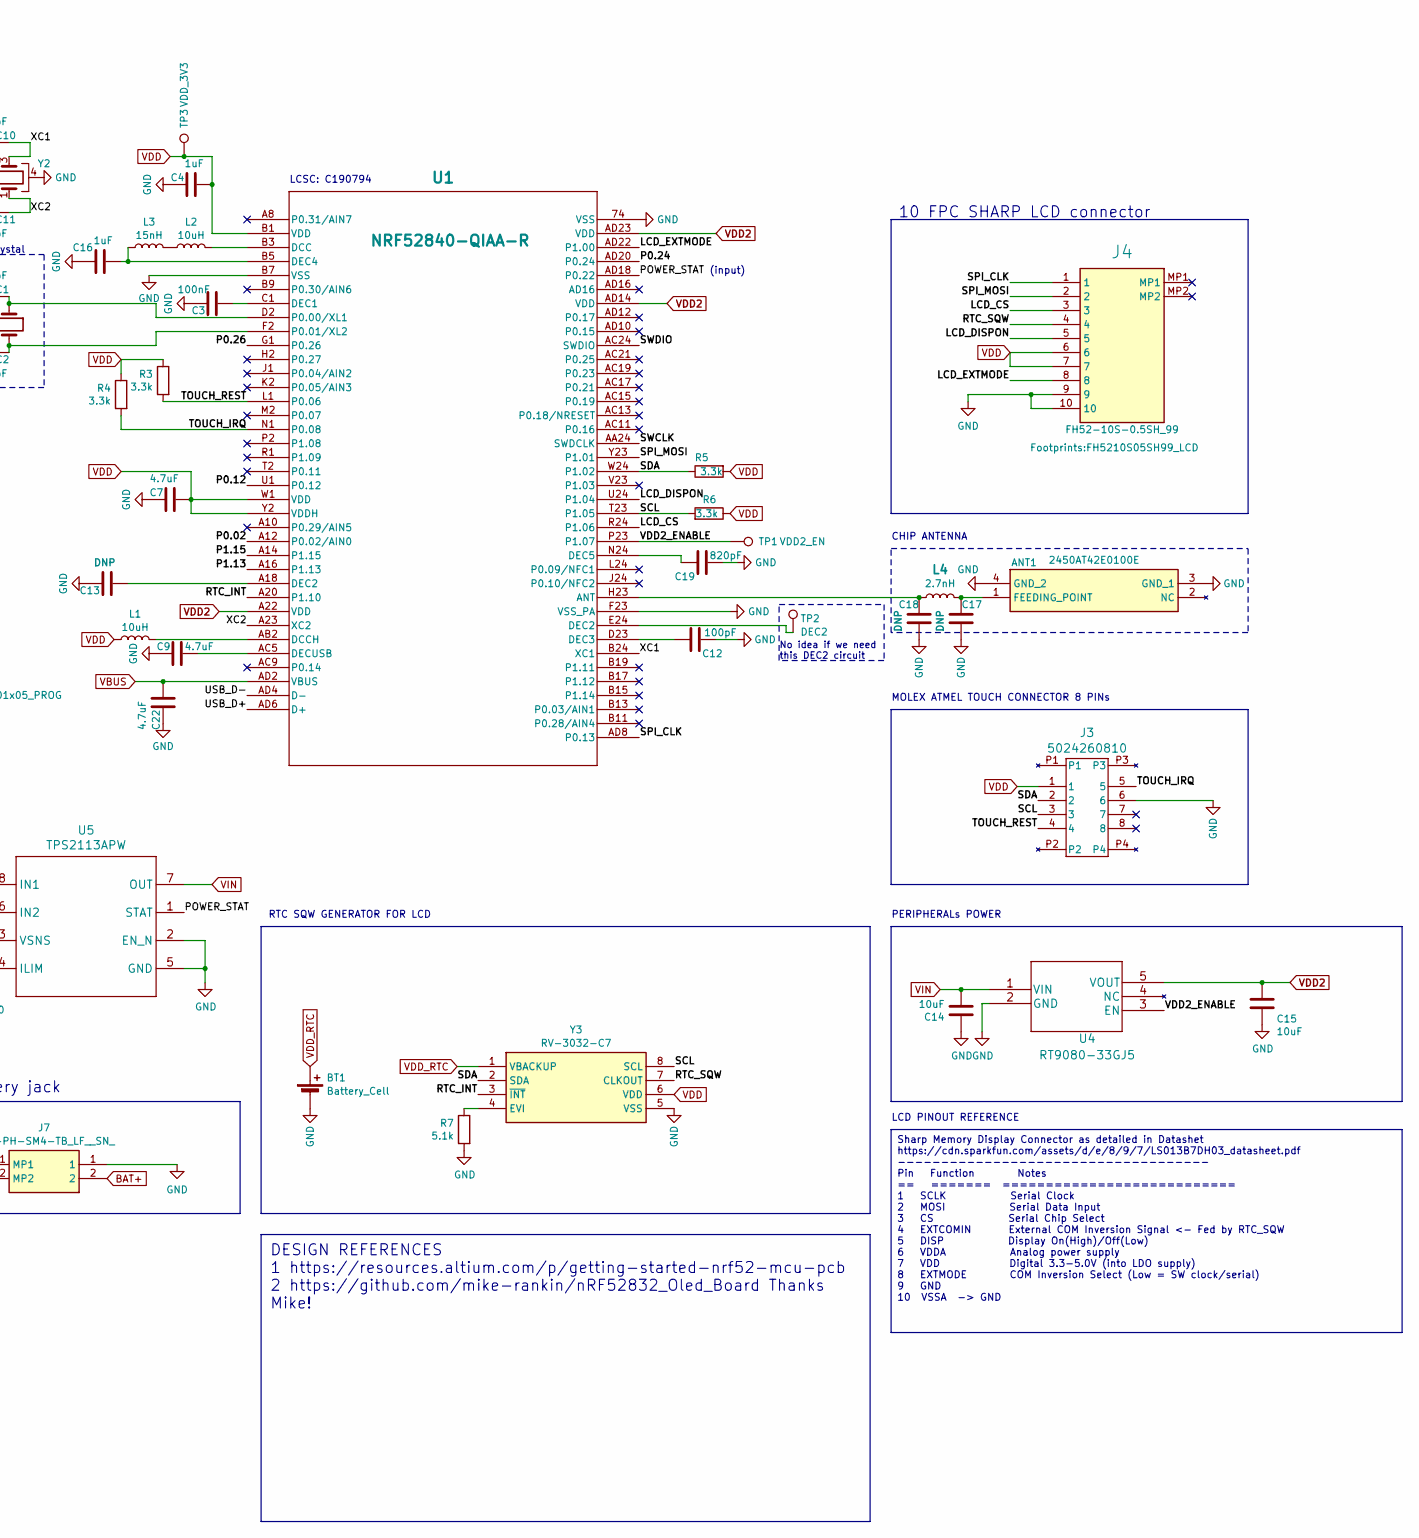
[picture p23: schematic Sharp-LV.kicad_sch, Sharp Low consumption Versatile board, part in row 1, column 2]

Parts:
ANT1: 2450AT42E0100E; 2450AT42E0100E-ANT; LCSC C3285081
BT1: Battery_Cell; CoinBattery_MS621FE; LCSC C80909
C1, C2, C10, C11: 12pF; C_0402_1005Metric; LCSC C386126
C3: 100nF; C_0402_1005Metric; LCSC C5137468
C4, C16: 1uF; C_0201_0603Metric; LCSC C97888
C5, C6, C14, C15: 10uF; C_0805_2012Metric; LCSC C15850
C7, C9, C22: 4.7uF; C_0402_1005Metric; LCSC C23733
C12: 100pF; C_0201_0603Metric; LCSC C531423
C13, C17, C18: DNP; C_0402_1005Metric; LCSC Leave empty
C19: 820pF; C_0402_1005Metric; LCSC C2891595
C20, C21: 100nF; C_0805_2012Metric; LCSC C49678
J1: USB_C_Receptacle_USB2.0; USB_C_Receptacle_HRO_TYPE-C-31-M-12; LCSC C165948
J2: Conn_01x05_PROG; PinHeader_1x05_P2.54mm_Vertical
J3: 5024260810; CON_Molex_5024260812; LCSC C563931
J4: FH52-10S-0.5SH_99; FH5210S05SH99_LCD; Manufacturer_Part_Number FH52-10S-0.5SH(99); JLCPCB Part # C598038
J5: SM04B-SRSS-TB_LF__SN_; QWIIC_SM04B-SRSS-TB_LFSN_; Manufacturer_Part_Number SM04B-SRSS-TB(LF)(SN); LCSC C160404
J6: Conn_2Rows-13Pins; Samtec_HLE-105-02-xxx-DV-A_2x05_P2.54mm_Horizontal
J7: S2B-PH-SM4-TB_LF__SN_; S2BPHSM4TBLFSN; Manufacturer_Part_Number S2B-PH-SM4-TB(LF)(SN); LCSC C295747
L1, L2: 10uH; L_0603_1608Metric; LCSC C373750
L3: 15nH; L_0603_1608Metric; LCSC C2757919
L4: 2.7nH; L_0603_1608Metric; LCSC C5252358
R1: 400; R_0603_1608Metric; LCSC C23151
R2, R7, R8: 5.1k; R_0603_1608Metric; LCSC C23186
R3, R4, R5, R6: 3.3k; R_0402_1005Metric; LCSC C5224103
TP1: VDD2_EN; TestPoint_Pad_D1.5mm
TP2: DEC2; TestPoint_Pad_D1.0mm
TP3: VDD_3V3; TestPoint_Pad_D1.5mm
U1: NRF52840-QIAA-R; NRF52840_AQFN73_7X7_NOR; LCSC C190794
U2: USBLC6-2P6; SOT-666; LCSC C2827693
U3: MCP1700-3302E_SOT23; SOT-23; LCSC C39051
U4: RT9080-33GJ5; TSOT-23-5; LCSC C841192
U5: TPS2113APW; TPS2113APWR; LCSC C130052
Y1: 32.768K; Crystal_SMD_3215-2Pin_3.2x1.5mm; LCSC C32346
Y2: Crystal 32Mhz; Crystal_SMD_2016-4Pin_2.0x1.6mm; LCSC C409316
Y3: RV-3032-C7; RV3032C7; Manufacturer_Part_Number RV-3032-C7; LCSC C5127802

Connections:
/LCD_CS: J4.3, U1.R24 (P1.06)
/LCD_DISPON: J4.5, U1.U24 (P1.04)
/LCD_EXTMODE: J4.8, U1.AD22 (P1.00)
/P0.02: J6.1, U1.A12 (P0.02/AIN0)
/P0.12: J6.10, U1.U1 (P0.12)
/P0.24: J6.7, U1.AD20 (P0.24)
/P0.26: J6.2, U1.G1 (P0.26)
/P1.13: J6.8, U1.A16 (P1.13)
/P1.15: J6.9, U1.A14 (P1.15)
/POWER_STAT: U1.AD18 (P0.22), U5.1 (STAT)
/RTC_INT: U1.A20 (P1.10), Y3.3 (~INT)
/RTC_SQW: J4.4, J6.6, Y3.7 (CLKOUT)
/SCL: J3.3, J5.1, R6.2, U1.T23 (P1.05), Y3.8 (SCL)
/SDA: J3.2, J5.2, R5.1, U1.W24 (P1.02), Y3.2 (SDA)
/SPI_CLK: J4.1, U1.AD8 (P0.13)
/SPI_MOSI: J4.2, U1.Y23 (P1.01)
/SWCLK: J2.5, U1.AA24 (SWDCLK)
/SWDIO: J2.4, U1.AC24 (SWDIO)
/TOUCH_IRQ: J3.5, J6.3, R4.2, U1.N1 (P0.08)
/TOUCH_REST: J3.4, R3.2, U1.L1 (P0.06)
/USB_D+: U1.AD6 (D+), U2.4 (I/O2)
/USB_D-: U1.AD4 (D-), U2.6 (I/O1)
/USB_IN_D+: J1.A6 (D+), J1.B6 (D+), U2.3 (I/O2)
/USB_IN_D-: J1.A7 (D-), J1.B7 (D-), U2.1 (I/O1)
/VDD2_ENABLE: TP1.1, U1.P23 (P1.07), U4.3 (EN)
/XC1: C10.2, U1.B24 (XC1), Y2.3
/XC2: C11.2, U1.A23 (XC2), Y2.1
BAT+: C21.2, J7.2, U5.6 (IN2)
GND: ANT1.3 (GND_1), ANT1.4 (GND_2), BT1.2 (-), C1.1, C2.1, C3.1, C4.1, C5.1, C6.1, C7.1, C9.1, C10.1, C11.1, C12.1, C13.1, C14.2, C15.1, C16.1, C17.1, C18.1, C19.2, C20.2, C21.1, C22.1, J1.A1 (GND), J1.A12 (GND), J1.B1 (GND), J1.B12 (GND), J1.S1 (SHIELD), J2.1, J3.6, J4.9, J4.10, J5.4, J6.5, J7.1, R1.2, R2.2, R7.2, R8.2, U1.74 (VSS), U1.B7 (VSS), U1.F23 (VSS_PA), U2.2 (GND), U3.1 (GND), U4.2 (GND), U5.2 (EN_N), U5.5 (GND), Y2.2, Y2.4, Y3.5 (VSS)
unnamed: ANT1.1 (FEEDING_POINT), C17.2, L4.2
unnamed: C13.2, U1.A18 (DEC2)
unnamed: J1.A5 (CC1), R8.1
unnamed: J1.B5 (CC2), R2.1
unnamed: L2.1, L3.2
unnamed: TP2.1, U1.E24 (DEC2)
unnamed: C18.2, L4.1, U1.H23 (ANT)
unnamed: L2.2, U1.B3 (DCC)
unnamed: L1.2, U1.AB2 (DCCH)
unnamed: C3.2, U1.C1 (DEC1)
unnamed: C12.2, U1.D23 (DEC3)
unnamed: C16.2, L3.1, U1.B5 (DEC4)
unnamed: C19.1, U1.N24 (DEC5)
unnamed: C9.2, U1.AC5 (DECUSB)
unnamed: C1.2, U1.D2 (P0.00/XL1), Y1.1
unnamed: C2.2, U1.F2 (P0.01/XL2), Y1.2
unnamed: R1.1, U5.4 (ILIM)
unnamed: R7.1, Y3.4 (EVI)
VBUS: C20.1, C22.2, J1.A4 (VBUS), J1.A9 (VBUS), J1.B4 (VBUS), J1.B9 (VBUS), U1.AD2 (VBUS), U2.5 (VBUS), U5.3 (VSNS), U5.8 (IN1)
VDD: C4.2, C6.2, C7.2, J2.3, J3.1, J4.6, J4.7, L1.1, R3.1, R4.1, R5.2, R6.1, TP3.1, U1.B1 (VDD), U1.W1 (VDD), U1.Y2 (VDDH), U3.2 (VO), Y3.6 (VDD)
VDD2: C15.2, J2.2, J5.3, J6.4, U1.A22 (VDD), U1.AD14 (VDD), U1.AD23 (VDD), U4.5 (VOUT)
VDD_RTC: BT1.1 (+), Y3.1 (VBACKUP)
VIN: C5.2, C14.1, U3.3 (VI), U4.1 (VIN), U5.7 (OUT)

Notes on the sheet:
DESIGN REFERENCES 1 https://resources.altium.com/p/getting-started-nrf52-mcu-pcb 2 https://github.com/mike-rankin/nRF52832_Oled_Board Thanks Mike!
Sharp Memory Display Connector as detailed in Datashet https://cdn.sparkfun.com/assets/d/e/8/9/7/LS013B7DH03_datasheet.pdf ------------------------------------ Pin Function Notes == ======= =========================== 1 SCLK Serial Clock 2 MOSI Serial Data Input 3 CS Serial Chip Select 4 EXTCOMIN E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
Pending TO-DOs 1 Add QWIIC I2C connector 2 Add TP4057 battery charger circuit 3 Or decide if Rel 1.0 should have this 4 IMPORTANT: Double check initial PROG SWDIO/SWCLK connectors
USB-C JTAG / CDC Serial to MCU
Power 3.3V MCU & TOUCH ONLY
No idea if we need this DEC2 circuit
10 FPC SHARP LCD connector
Battery jack
PERIPHERALs POWER
INITIAL PROG HEADER:
CHIP ANTENNA
LCD PINOUT REFERENCE
(input)
LCSC: C190794
MOLEX ATMEL TOUCH CONNECTOR 8 PINs
RTC SQW GENERATOR FOR LCD
Optional: RTC Crystal
QWIIC Connector (I2C) & Test header connections
POWER, Battery or USB ?

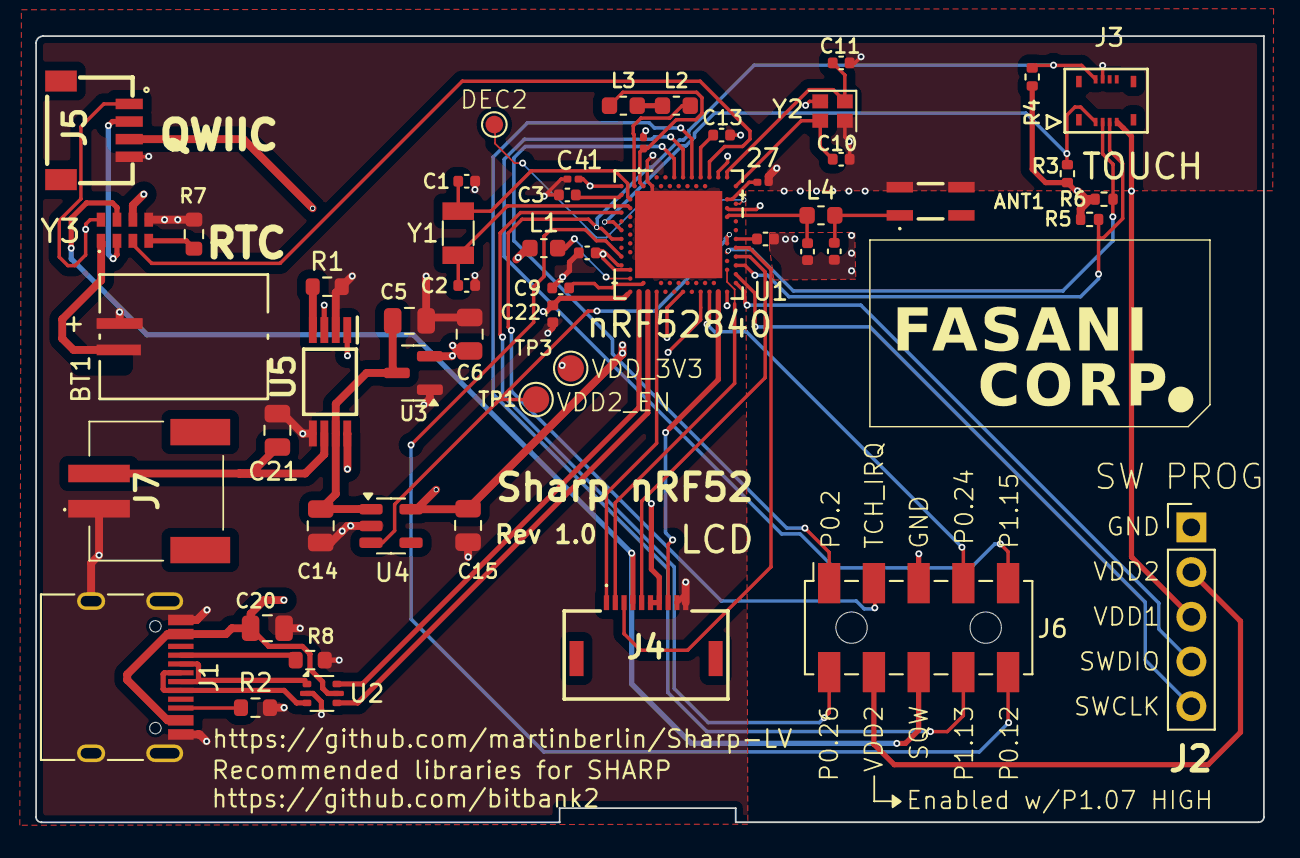
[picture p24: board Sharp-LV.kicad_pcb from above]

Board: 4 copper layers, 69.7 x 44.7 mm, 53 parts (0 on the bottom side), 52 nets.

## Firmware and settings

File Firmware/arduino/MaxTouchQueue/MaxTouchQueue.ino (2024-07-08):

#include <bb_captouch.h>
#include <Wire.h>
#include <OneBitDisplay.h>
#include "freertos/queue.h"
#define DEBUG_VERBOSE false

ONE_BIT_DISPLAY obd;

#define LCD_DISPON 4
#define LCD_EXTMODE 14

#define CS_PIN 3
#define MOSI_PIN 2
#define CLK_PIN 1

#define BITBANG 0
uint8_t ucBackBuf[400*240/8];

TOUCHINFO ti;
BBCapTouch bbct;
int iWidth, iHeight;

#define TOUCH_SDA 7
#define TOUCH_SCL 8
#define TOUCH_INT 6
#define TOUCH_RST 0

static QueueHandle_t gpio_evt_queue = NULL;
static QueueHandle_t touch_queue = NULL;

#define TOUCH_QUEUE_LENGTH 12  // Try not to make it super large
struct xydata {
	uint16_t x;
	uint16_t y;
} xy_data;

int numints = 0;

void IRAM_ATTR touch_isr() {
	numints++;
  xQueueSendFromISR(gpio_evt_queue, &numints, NULL);
}

/* this function will be invoked when additionalTask was created */
void ISRprocessing( void * parameter )
{
  uint32_t io_num;
  /* loop forever */
  while (1) {
  
    if (xQueueReceive(gpio_evt_queue, &io_num, portMAX_DELAY)) {
      if (bbct.getSamples(&ti)) {
          xy_data.x = ti.x[0];
          xy_data.y = ti.y[0];

          if (xQueueSend( touch_queue, &xy_data, ( TickType_t ) 0 ) == pdTRUE) {
                // The message was sent successfully
            } else {
                Serial.println("ERR: Could not add xy_data in queue");
            }
      } 
    }     
  }
  // Should never get out
  vTaskDelete( NULL );
}

void setup() {
  //create a queue to handle gpio event from isr
  gpio_evt_queue = xQueueCreate(TOUCH_QUEUE_LENGTH, sizeof(uint8_t));
  touch_queue = xQueueCreate(TOUCH_QUEUE_LENGTH, sizeof(xy_data));

  pinMode(TOUCH_INT, INPUT_PULLUP);
  attachInterrupt(TOUCH_INT, touch_isr, FALLING);

  pinMode(LCD_EXTMODE, OUTPUT);
  pinMode(LCD_DISPON, OUTPUT);
  digitalWrite(LCD_DISPON, 1);
  digitalWrite(LCD_EXTMODE, 1);
  
  Serial.begin(115200);

  obd.setSPIPins(CS_PIN, MOSI_PIN, CLK_PIN, -1);
  obd.SPIbegin(SHARP_400x240, 6000000L);
  obd.setBuffer(ucBackBuf);
  obd.fillScreen(OBD_BLACK);
  obd.setFont(FONT_16x16);
  obd.setTextColor(OBD_WHITE);
  obd.println();
  obd.println("SOFTWARE: bitbank LARRY");
  obd.println();
  obd.println("HARDWARE: Fasani Corp.");
  obd.display();
  delay(1000);
  obd.fillScreen(OBD_WHITE);
  obd.display();
  Serial.println("Test this TOUCH");

  bbct.init(TOUCH_SDA, TOUCH_SCL, TOUCH_RST, TOUCH_INT);
  int iType = bbct.sensorType();
  Serial.printf("Sensor type = %d\n", iType);

    xTaskCreate(
    ISRprocessing,           /* Task function. */
    "ISRprocessing",        /* name of task. */
    8000,                    /* Stack size of task */
    NULL,                     /* parameter of the task */
    5,                        /* priority of the task */
    NULL);  
    
}

void loop() {
    /* Read from the touch Queue */
    if( xQueueReceive(touch_queue, &xy_data, ( TickType_t ) 0 ) ) {
      #if DEBUG_VERBOSE
        Serial.print("Touch ");Serial.print(i+1);Serial.print(": ");;
        Serial.print("  x: ");Serial.print(ti.x[i]);
        Serial.print("  y: ");Serial.print(ti.y[i]);
        Serial.print("  size: ");Serial.println(ti.area[i]);
      #endif
    
        obd.fillCircle(xy_data.y, xy_data.x, 4, OBD_BLACK);
        obd.display();
        //Serial.printf("num INTs:%d\n", numints);
      }  
}

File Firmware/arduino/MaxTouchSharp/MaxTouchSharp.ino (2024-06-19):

#include <bb_captouch.h>
#include <Wire.h>

BBCapTouch bbct;
int iWidth, iHeight;

#define TOUCH_SDA 0
#define TOUCH_SCL 1
#define TOUCH_INT 2
#define TOUCH_RST 3

void setup() {
  pinMode(TOUCH_INT, INPUT_PULLUP);
  Serial.begin(115200);
  Serial.println("Let'S test this TOUCH");

  bbct.init(TOUCH_SDA, TOUCH_SCL, TOUCH_RST, TOUCH_INT);
  int iType = bbct.sensorType();
  Serial.printf("Sensor type = %d\n", iType);
}

TOUCHINFO ti;

void loop() {
  if (bbct.getSamples(&ti)) {
    for (int i=0; i<ti.count; i++){
      Serial.print("Touch ");Serial.print(i+1);Serial.print(": ");;
      Serial.print("  x: ");Serial.print(ti.x[i]);
      Serial.print("  y: ");Serial.print(ti.y[i]);
      Serial.print("  size: ");Serial.println(ti.area[i]);
      Serial.println(' ');
    } // for each touch point
  }
  // INT Seems to be unuseful, is always LOW, maybe needs external PullUP?
  // if (digitalRead(TOUCH_INT) == 0) {
  //   Serial.println("Touched");
  // }


}

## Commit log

2024-05-29 Initial push
    [2450AT42E0100E-ANT.stp, MOLEX_502426-0810.stp, NRF52840-QIAA-R.stp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]
2024-05-29 1.0 starting to take shape: Add LCD & touch CONN
    [LCD-10S-0.5SH.step, Sharp-LV.kicad_sch, USB_TYPE-C-31-M-12.step]
2024-05-29 Release 1.0 pending review
    [CoinBattery_MS621FE-FL11E.stp, RV-3032-C7.stp, Sharp-LV.kicad_pcb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]
2024-05-30 Revision 1.0 silk
    [Sharp-LV.kicad_pcb, Sharp-LV.kicad_sch]
2024-06-07 Firmware probes
2024-06-07 Working I2C scanner in Zephyr
2024-06-07 Switch to md
2024-06-11 Add QWIIC & headers
    [QWIIC_SM04B-SRSS-TB_LF__SN_.stp, Sharp-LV.kicad_pcb, Sharp-LV.kicad_sch]
2024-06-12 Add power mux TPS2113
    [Sharp-LV.kicad_pcb, Sharp-LV.kicad_sch, TPS2113APWR.stp]
2024-06-13 Update battery connector & add SCH pdf
    [S2B-PH-SM4-TB_LF__SN_.stp, Sharp-LV.kicad_pcb, Sharp-LV.kicad_sch]
2024-06-14 Update crystal to the one provided by Mike (32 Mhz)
    [Sharp-LV.kicad_pcb, Sharp-LV.kicad_sch]
2024-06-14 update schematic
    [Sharp-LV.kicad_sch]
2024-06-16 Update SCH and add C22 to VUSB
    [Sharp-LV.kicad_pcb, Sharp-LV.kicad_sch]
2024-06-16 Update SCH & DRC
    [Sharp-LV.kicad_pcb, Sharp-LV.kicad_sch]
2024-06-18 Update schematics
2024-06-18 Add GND pane
    [Sharp-LV.kicad_pcb, Sharp-LV.kicad_sch]
2024-06-19 Add Arduino sketch for bb_Captouch
2024-06-20 Update S3 routing proposal
    [2450AT42E0100E-ANT.stp, BOM.xlsx, Crytal_ECS-40Mhz_ECS.step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]
2024-06-20 Update S3 silk
    [S3-silicon-Sharp-Touch.kicad_pcb]
2024-06-25 1.0 sent to fabrication
    [BOM.xlsx, BOMs.xlsx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]
2024-06-26 Update BT1 routing because bad polarity
    [S3-silicon-Sharp-Touch.kicad_pcb, Sharp-LV.kicad_pcb]
2024-06-27 Move touch 2 mm right
    [BOMs.xlsx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]
2024-07-06 Corrections heading to Rev 1.1 (Bottom ROW of Touch RIGHT!)
    [S3-silicon-Sharp-Touch.kicad_pcb, S3-silicon-Sharp-Touch.kicad_sch]
2024-07-06 Update TOUCH pinout in PCBs
    [S3-silicon-Sharp-Touch.kicad_pcb, S3-silicon-Sharp-Touch.kicad_sch, Sharp-LV.kicad_pcb]
2024-07-07 Heading for Rel 1.1
    [S3-silicon-Sharp-Touch.kicad_pcb, S3-silicon-Sharp-Touch.kicad_sch, Sharp-LV.kicad_sch]
2024-07-10 S3 release 1.1 is ready
    [S3-silicon-Sharp-Touch.kicad_pcb, S3-silicon-Sharp-Touch.kicad_sch]
2024-07-17 S3 PCB 3D stl file
    [S3-silicon-Sharp-Touch-3D.stl, S3-silicon-Sharp-Touch.kicad_pcb]
2024-07-18 Add 3D printable enclosure
    [SHARP-S3-battery-BOTTOM.stl, SHARP-S3-battery-TOP.stl, SHARP-S3-battery.blend]
2024-07-18 Update top enclosure
    [SHARP-S3-battery-TOP.stl]
2024-07-18 Create FUNDING.yml
    If you like this PCB then we will appreciate you get one from our store
2024-07-19 Update TOP enclosure with touch cavity
    [SHARP-S3-battery-TOP.stl]
2024-07-19 Update RTC with RV-3032
    [S3-silicon-Sharp-Touch.kicad_pcb, S3-silicon-Sharp-Touch.kicad_sch]

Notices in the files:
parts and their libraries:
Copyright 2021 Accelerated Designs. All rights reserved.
